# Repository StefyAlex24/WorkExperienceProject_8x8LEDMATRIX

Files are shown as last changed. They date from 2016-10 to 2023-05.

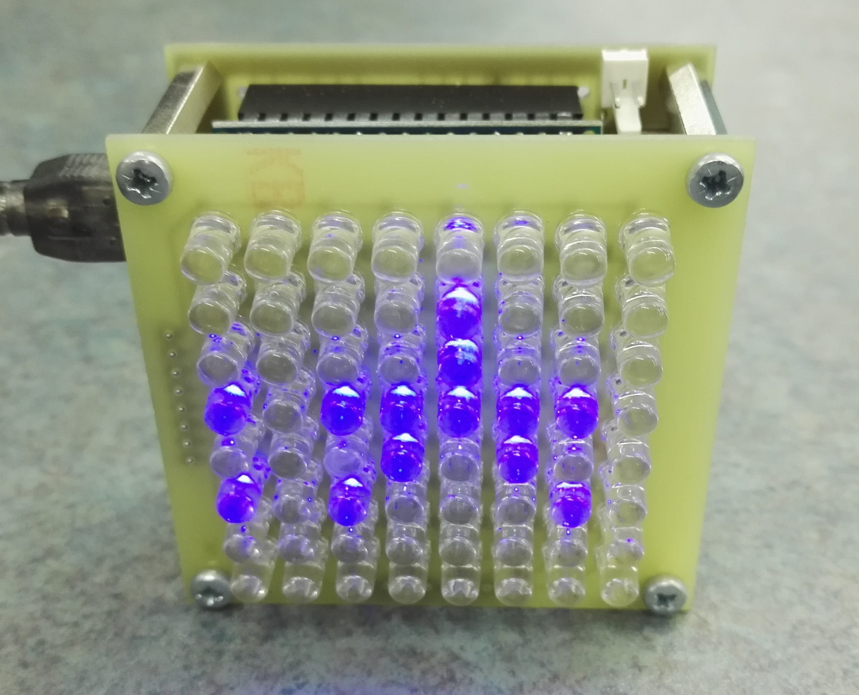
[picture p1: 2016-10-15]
front.jpg

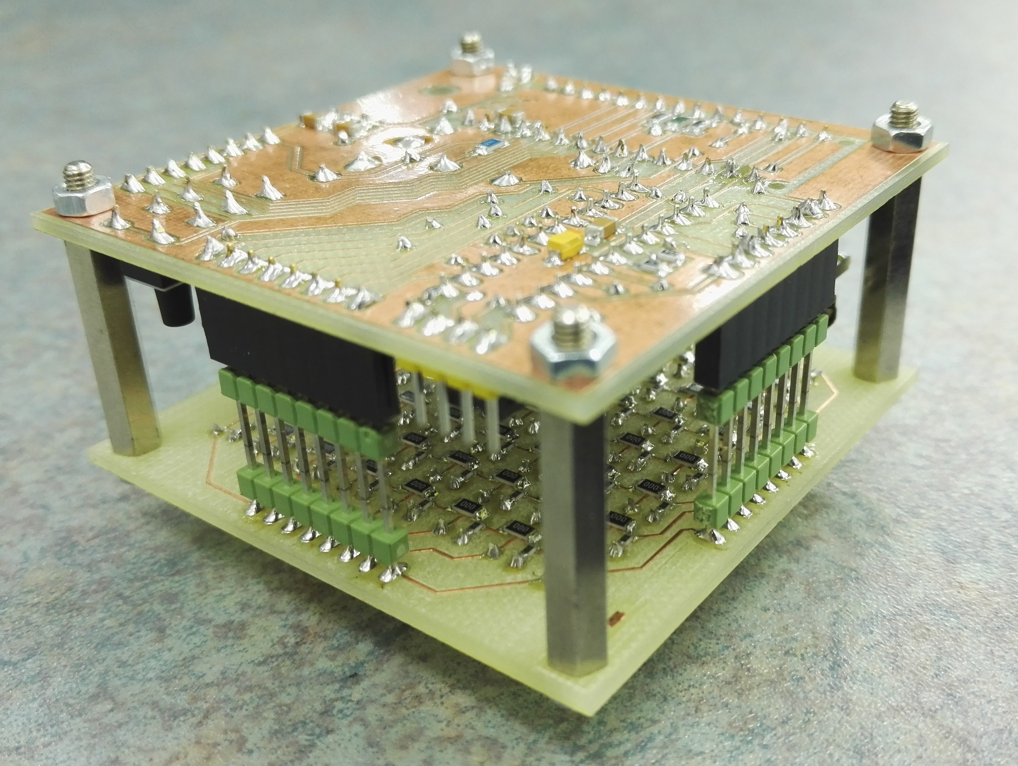
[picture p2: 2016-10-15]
upsidedown.jpg

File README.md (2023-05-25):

# WorkExperienceProject_8x8LEDMATRIX

Arduino Nano based 8x8 LED matrix board with MAX7219 Controller.
Refer to file: 8x8 LED Matrix.docx for project info.
Also includes Arduino Code files to get you started on your journey.

This project is intended as a work experience assignment for school children of age 14 and over.
The code for this project is based off other open source examples with only minor additions and modifications.

Forking of this project is encouraged.

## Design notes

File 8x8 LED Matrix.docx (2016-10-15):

8x8 LED Matrix – Work Experience Project.

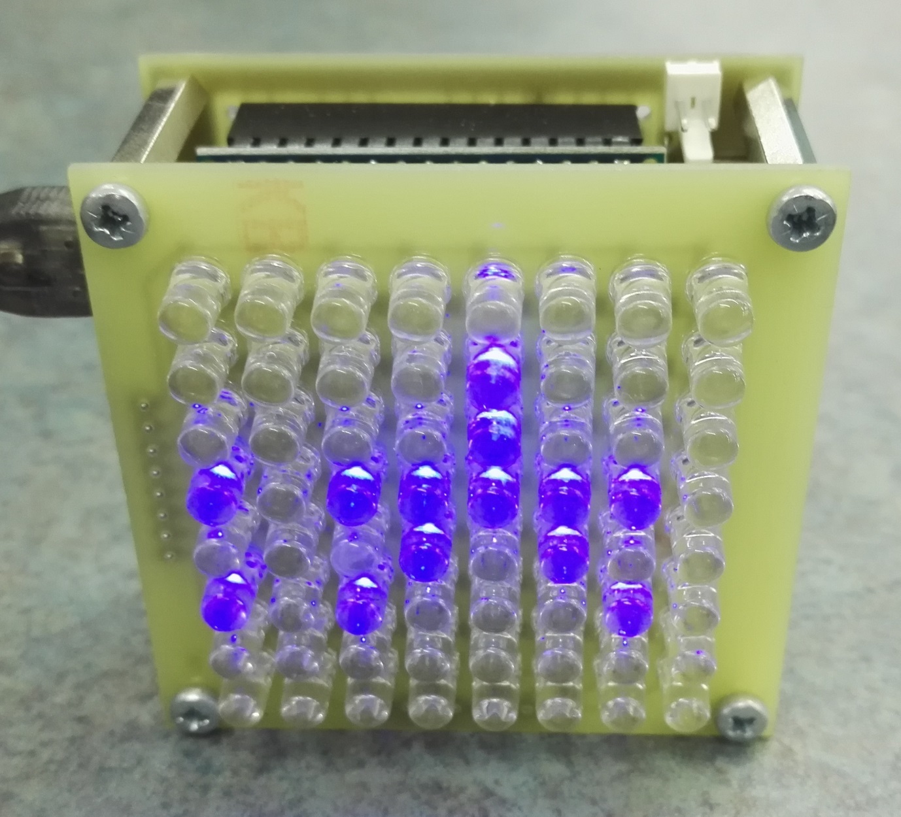
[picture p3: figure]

Objective:

To build an LED matrix board that will display a number of custom messages and (roughly) display the current room temperature.

Skills required:

Component identification, soldering, assembly and programming.

Overview:

Two circuit boards will need to be routed on the PCB router, one for the LED board and the other for the control board. Once populated, both boards will be connected together to create one functional unit.

The first stage is to populate the LED board with 64 5mm LEDs and accompanying current limiting resistors followed by two sets of 2.54mm pitch pin headers.

The LEDs are polarised and must be inserted into the board in the correct orientation before soldering.

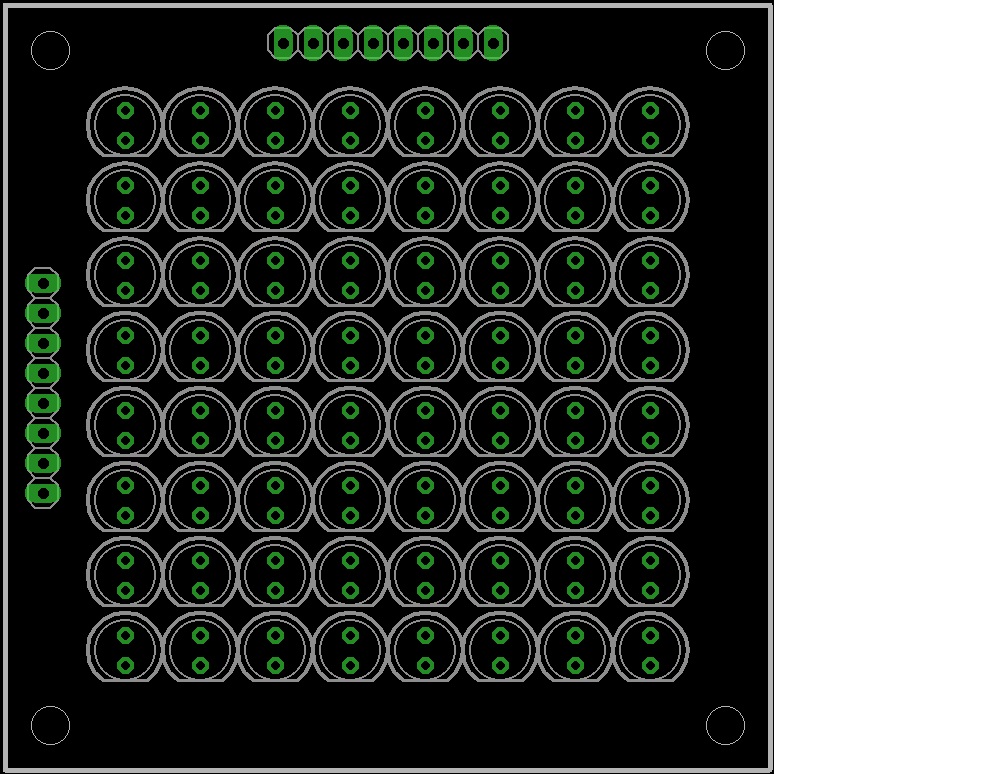
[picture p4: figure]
Z:\WORK EXPERIENCE\8X8 LED MATRIX\BUILD\8X8 TOP PLACEMENT.dib

(This image is a top view of the LED board.)

The resistors should now be soldered on to the underside of the board, the smaller 0603 sized resistors are for current limiting and the larger 1206 sized resisters are 0 ohm jumpers.

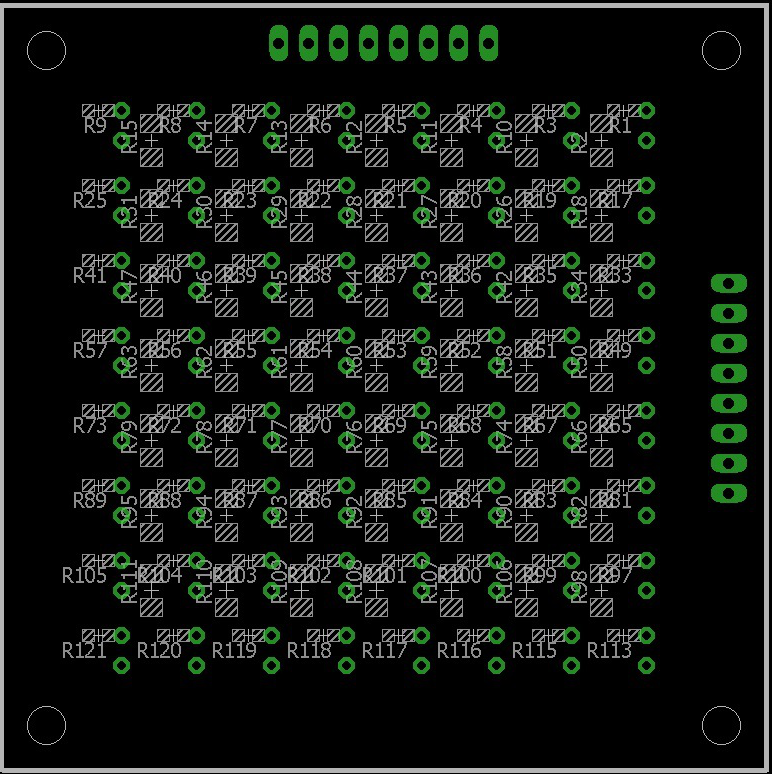
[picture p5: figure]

Next, the headers on the LED board should be soldered into position.

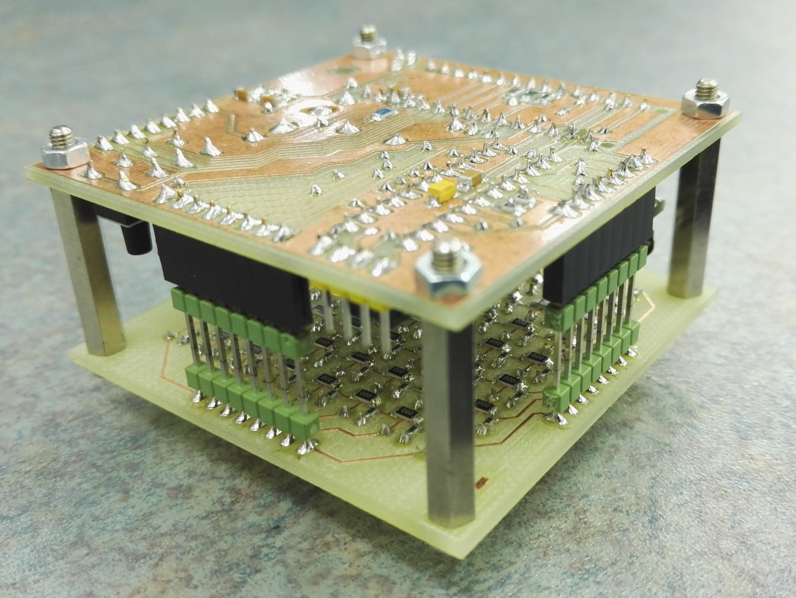
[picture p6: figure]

A small strip of masking tape placed over the holes will help align the pins; they should be flush to the top of the board on the LED side and not standing proud.

Now that the LED board is complete we will move on to the control board.

The control board incorporates a separate micro controller board (Arduino Nano), MAX7219 LED controller chip, power supply, buzzer, thermistor (temperature sensor), push buttons and two extra connectors for future expansion.

All components should be gathered and identified ready for soldering.

Surface mount devices should be soldered first, followed by link wires then through leaded parts; these should be soldered in size order starting from smallest to largest.

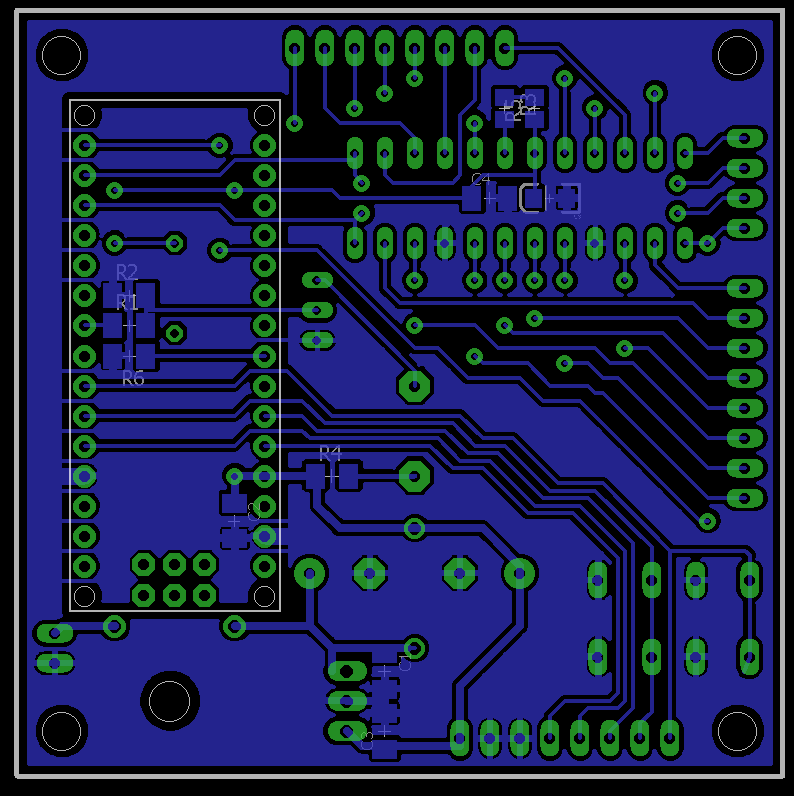
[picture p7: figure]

(This is a view of the underside of the control board.)

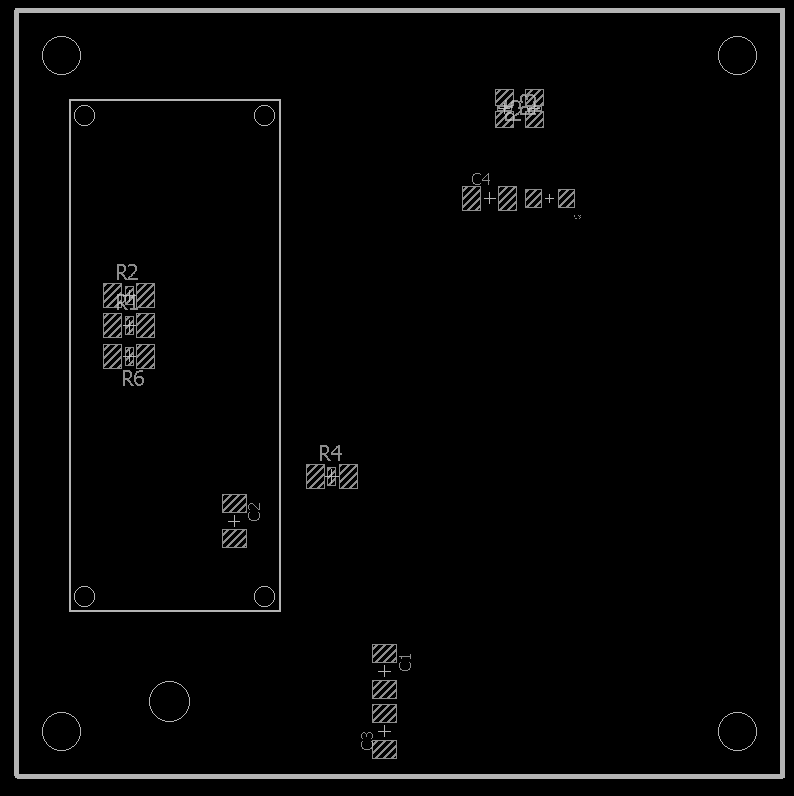
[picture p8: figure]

(This image details the bottom side SMD placement on the control board.)

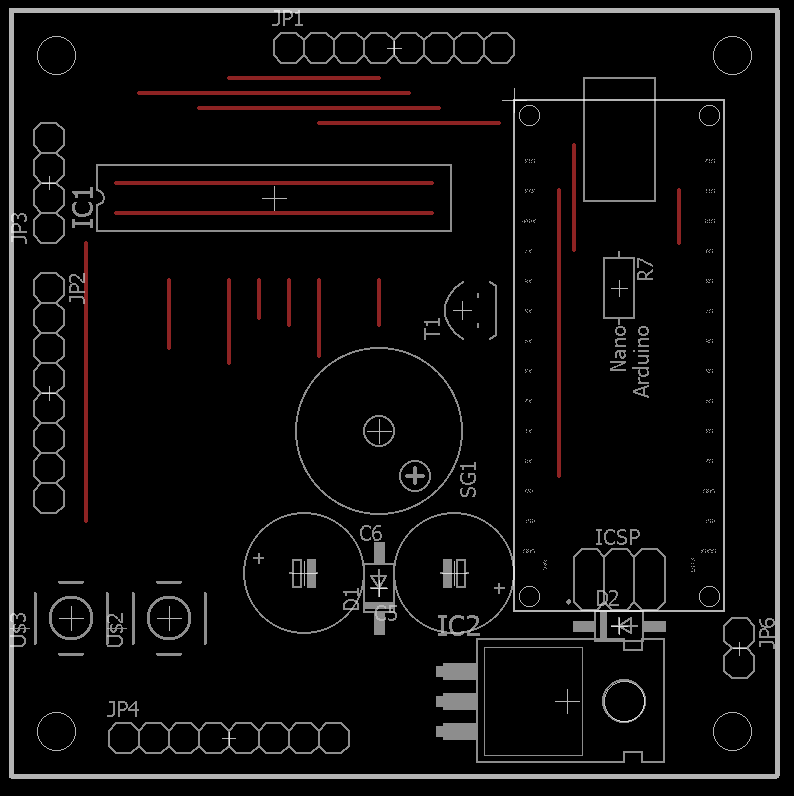
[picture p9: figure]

(The red lines in the above image are link wires that must be placed on top of the board and soldered underneath.)

Once this stage has been completed and checked for errors we will then assemble and program the Arduino board. An Arduino “sketch” and libraries will be provided; at this point you will be able to add up to 9 custom messages to display on the matrix. The sketch will then be compiled and uploaded to the Arduino board using the Arduino IDE software.

Connect the Arduino to the control board; mount the two boards together with 25mm hex pillars and M3 screws. Plug in the USB cable to provide power to the unit.

Messages can be sent to the Arduino over a serial connection at 9600 baud. The serial message will be displayed as string0 in the sketch.

Project info:

Here are the project schematics and parts lists:

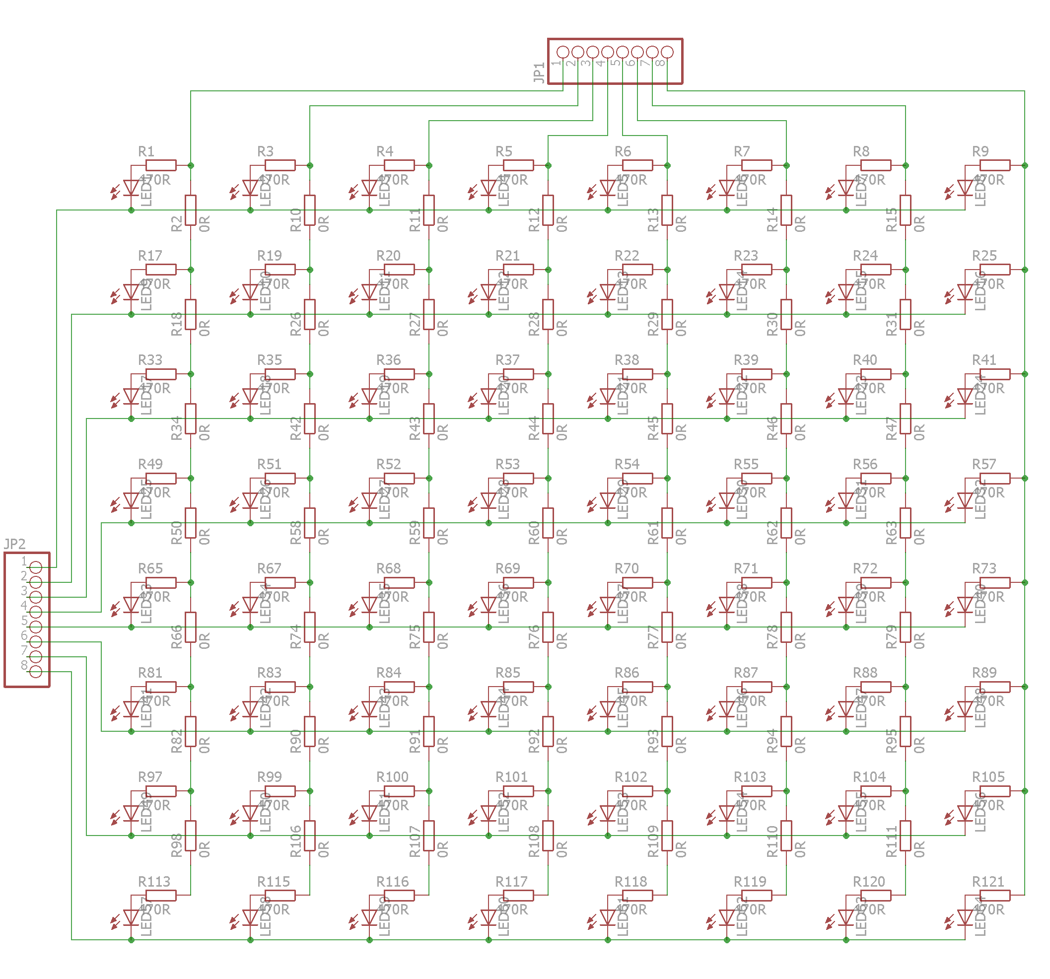
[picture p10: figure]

For the LED board, only four different types of component are used, only the LEDs have a polarity and because the two types of resistors are also different sizes, it would be very hard to build this board incorrectly.

LED5MM led

470R R0603

0R R1206

1X08 pinhead

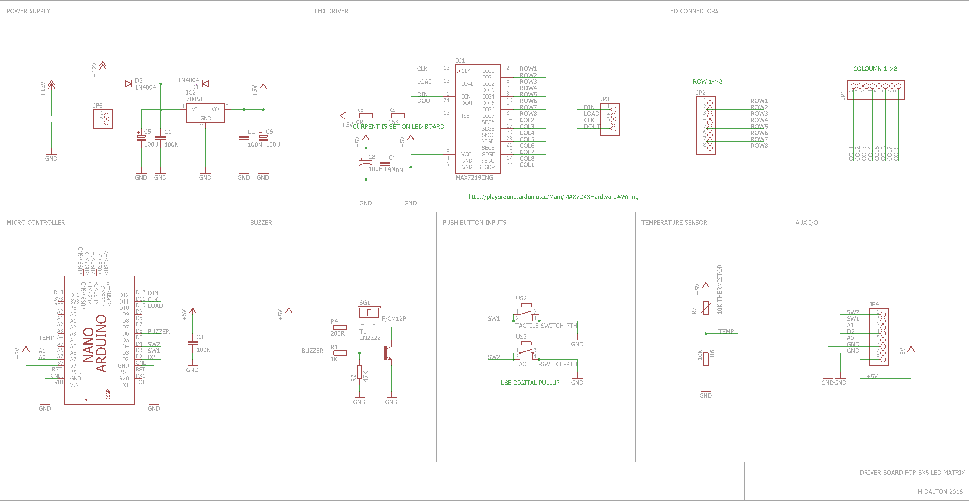
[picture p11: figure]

This is the parts list for the driver board.

Partlist

Part Value Device Package

C1 100N C-EUC1206K C1206K

C2 100N C-EUC1206K C1206K

C3 100N C-EUC1206K C1206K

C4 100N C-EUC1206K C1206K

C5 100U CPOL-EUE5-10.5 E5-10,5

C6 100U CPOL-EUE5-10.5 E5-10,5

C8 10uF TANT 10UF-TANT EIA3216

D1 1N4004 1N4004 DO41-10

D2 1N4004 1N4004 DO41-10

IC1 MAX7219CNG MAX7219CNG DIL24-3

IC2 7805T 7805T TO220H

JP1 PINHD-1X8 1X08

JP2 PINHD-1X8 1X08

JP3 PINHD-1X4 1X04

JP4 PINHD-1X8 1X08

JP6 PINHD-1X2 1X02

PCB1 ARDUINO ARDUINO_NANO ARDUINO_NANO

R1 1K R-EU_M1206 M1206

R2 47K R-EU_M1206 M1206

R3 15K R-EU_M0805 M0805

R4 200R R-EU_M1206 M1206

R5 0R R-EU_M0805 M0805

R6 10K R-EU_M1206 M1206

R7 10K THERMISTOR-7,5 R-7,5

SG1 F/CM12P BUZZER F/CM12P

T1 2N2222 2N2222 TO92-EBC-OVAL

U$2 SWITCH TACTILE-SWITCH-PTH TAC-SWITCH-PTH

U$3 SWITCH TACTILE-SWITCH-PTH TAC-SWITCH-PTH

Extra features:

The control board has some unused hardware for future expansion.

Two momentary push buttons and a buzzer are connected to the Arduino as well as an expansion header for both the Arduino and the Maxim LED driver chip. Extra features may be added into the code for greater functionality.

Multiple LED matrixes may be daisy chained and controlled by the Arduino as long as each matrix has its own controller IC.

A two pin power connector is present to allow the unit to be powered by a 9V battery; this connector is connected to a linear 5 volt regulator which will power both the LED and control boards.

The Code:

The following is the exact code used in this project. It is dependent on the MaxMatrix library made by Oscar Kin-Chung Au. (https://code.google.com/archive/p/arudino-maxmatrix-library/downloads)

Arduino IDE Download links: https://www.arduino.cc/en/Main/Software & http://www.arduino.org/downloads

The entire project can be viewed at: https://github.com/SlyMike/WorkExperienceProject_8x8LEDMATRIX

/*

# 8x8 LED matrix with temperature measurement and serial input. #

# Code taken from Marcelo Moraes, July 9th, 2013 & Arduino playground. #

# visit this web page for further information about MaxMatrix library #

# https://code.google.com/p/arudino-maxmatrix-library/ #

# This code is a public example. #

# Rehashed by Mick Dalton, 2016. #

*/

#include <MaxMatrix.h>

#include <avr/pgmspace.h>

//thermistor start

#include <math.h>

double ThermistorC(int RawADC) {

double Temp;

Temp = log(10000.0 * ((1024.0 / RawADC - 1)));

Temp = 1 / (0.001129148 + (0.000234125 + (0.0000000876741 * Temp * Temp )) * Temp );

Temp = Temp - 273.15;

return Temp;

}//thermistor end

PROGMEM const char CH[] = {

3, 8, B00000000, B00000000, B00000000, B00000000, B00000000, // space

1, 8, B01011111, B00000000, B00000000, B00000000, B00000000, // !

3, 8, B00000011, B00000000, B00000011, B00000000, B00000000, // "

5, 8, B00010100, B00111110, B00010100, B00111110, B00010100, // #

4, 8, B00100100, B01101010, B00101011, B00010010, B00000000, // $

5, 8, B01100011, B00010011, B00001000, B01100100, B01100011, // %

5, 8, B00110110, B01001001, B01010110, B00100000, B01010000, // &

1, 8, B00000011, B00000000, B00000000, B00000000, B00000000, // '

3, 8, B00011100, B00100010, B01000001, B00000000, B00000000, // (

3, 8, B01000001, B00100010, B00011100, B00000000, B00000000, // )

5, 8, B00101000, B00011000, B00001110, B00011000, B00101000, // *

5, 8, B00001000, B00001000, B00111110, B00001000, B00001000, // +

2, 8, B10110000, B01110000, B00000000, B00000000, B00000000, // ,

4, 8, B00001000, B00001000, B00001000, B00001000, B00000000, // -

2, 8, B01100000, B01100000, B00000000, B00000000, B00000000, // .

4, 8, B01100000, B00011000, B00000110, B00000001, B00000000, // /

4, 8, B00111110, B01000001, B01000001, B00111110, B00000000, // 0

3, 8, B01000010, B01111111, B01000000, B00000000, B00000000, // 1

4, 8, B01100010, B01010001, B01001001, B01000110, B00000000, // 2

4, 8, B00100010, B01000001, B01001001, B00110110, B00000000, // 3

4, 8, B00011000, B00010100, B00010010, B01111111, B00000000, // 4

4, 8, B00100111, B01000101, B01000101, B00111001, B00000000, // 5

4, 8, B00111110, B01001001, B01001001, B00110000, B00000000, // 6

4, 8, B01100001, B00010001, B00001001, B00000111, B00000000, // 7

4, 8, B00110110, B01001001, B01001001, B00110110, B00000000, // 8

4, 8, B00000110, B01001001, B01001001, B00111110, B00000000, // 9

2, 8, B01010000, B00000000, B00000000, B00000000, B00000000, // :

2, 8, B10000000, B01010000, B00000000, B00000000, B00000000, // ;

3, 8, B00010000, B00101000, B01000100, B00000000, B00000000, // <

3, 8, B00010100, B00010100, B00010100, B00000000, B00000000, // =

3, 8, B01000100, B00101000, B00010000, B00000000, B00000000, // >

4, 8, B00000010, B01011001, B00001001, B00000110, B00000000, // ?

5, 8, B00111110, B01001001, B01010101, B01011101, B00001110, // @

4, 8, B01111110, B00010001, B00010001, B01111110, B00000000, // A

4, 8, B01111111, B01001001, B01001001, B00110110, B00000000, // B

4, 8, B00111110, B01000001, B01000001, B00100010, B00000000, // C

4, 8, B01111111, B01000001, B01000001, B00111110, B00000000, // D

4, 8, B01111111, B01001001, B01001001, B01000001, B00000000, // E

4, 8, B01111111, B00001001, B00001001, B00000001, B00000000, // F

4, 8, B00111110, B01000001, B01001001, B01111010, B00000000, // G

4, 8, B01111111, B00001000, B00001000, B01111111, B00000000, // H

3, 8, B01000001, B01111111, B01000001, B00000000, B00000000, // I

4, 8, B00110000, B01000000, B01000001, B00111111, B00000000, // J

4, 8, B01111111, B00001000, B00010100, B01100011, B00000000, // K

4, 8, B01111111, B01000000, B01000000, B01000000, B00000000, // L

5, 8, B01111111, B00000010, B00001100, B00000010, B01111111, // M

5, 8, B01111111, B00000100, B00001000, B00010000, B01111111, // N

4, 8, B00111110, B01000001, B01000001, B00111110, B00000000, // O

4, 8, B01111111, B00001001, B00001001, B00000110, B00000000, // P

4, 8, B00111110, B01000001, B01000001, B10111110, B00000000, // Q

4, 8, B01111111, B00001001, B00001001, B01110110, B00000000, // R

4, 8, B01000110, B01001001, B01001001, B00110010, B00000000, // S

5, 8, B00000001, B00000001, B01111111, B00000001, B00000001, // T

4, 8, B00111111, B01000000, B01000000, B00111111, B00000000, // U

5, 8, B00001111, B00110000, B01000000, B00110000, B00001111, // V

5, 8, B00111111, B01000000, B00111000, B01000000, B00111111, // W

5, 8, B01100011, B00010100, B00001000, B00010100, B01100011, // X

5, 8, B00000111, B00001000, B01110000, B00001000, B00000111, // Y

4, 8, B01100001, B01010001, B01001001, B01000111, B00000000, // Z

2, 8, B01111111, B01000001, B00000000, B00000000, B00000000, // [

4, 8, B00000001, B00000110, B00011000, B01100000, B00000000, // \ backslash

2, 8, B01000001, B01111111, B00000000, B00000000, B00000000, // ]

3, 8, B00000010, B00000001, B00000010, B00000000, B00000000, // hat

4, 8, B01000000, B01000000, B01000000, B01000000, B00000000, // _

2, 8, B00000001, B00000010, B00000000, B00000000, B00000000, // `

4, 8, B00100000, B01010100, B01010100, B01111000, B00000000, // a

4, 8, B01111111, B01000100, B01000100, B00111000, B00000000, // b

4, 8, B00111000, B01000100, B01000100, B00101000, B00000000, // c

4, 8, B00111000, B01000100, B01000100, B01111111, B00000000, // d

4, 8, B00111000, B01010100, B01010100, B00011000, B00000000, // e

3, 8, B00000100, B01111110, B00000101, B00000000, B00000000, // f

4, 8, B10011000, B10100100, B10100100, B01111000, B00000000, // g

4, 8, B01111111, B00000100, B00000100, B01111000, B00000000, // h

3, 8, B01000100, B01111101, B01000000, B00000000, B00000000, // i

4, 8, B01000000, B10000000, B10000100, B01111101, B00000000, // j

4, 8, B01111111, B00010000, B00101000, B01000100, B00000000, // k

3, 8, B01000001, B01111111, B01000000, B00000000, B00000000, // l

5, 8, B01111100, B00000100, B01111100, B00000100, B01111000, // m

4, 8, B01111100, B00000100, B00000100, B01111000, B00000000, // n

4, 8, B00111000, B01000100, B01000100, B00111000, B00000000, // o

4, 8, B11111100, B00100100, B00100100, B00011000, B00000000, // p

4, 8, B00011000, B00100100, B00100100, B11111100, B00000000, // q

4, 8, B01111100, B00001000, B00000100, B00000100, B00000000, // r

4, 8, B01001000, B01010100, B01010100, B00100100, B00000000, // s

3, 8, B00000100, B00111111, B01000100, B00000000, B00000000, // t

4, 8, B00111100, B01000000, B01000000, B01111100, B00000000, // u

5, 8, B00011100, B00100000, B01000000, B00100000, B00011100, // v

5, 8, B00111100, B01000000, B00111100, B01000000, B00111100, // w

5, 8, B01000100, B00101000, B00010000, B00101000, B01000100, // x

4, 8, B10011100, B10100000, B10100000, B01111100, B00000000, // y

3, 8, B01100100, B01010100, B01001100, B00000000, B00000000, // z

3, 8, B00001000, B00110110, B01000001, B00000000, B00000000, // {

1, 8, B01111111, B00000000, B00000000, B00000000, B00000000, // |

3, 8, B01000001, B00110110, B00001000, B00000000, B00000000, // }

4, 8, B00001000, B00000100, B00001000, B00000100, B00000000, // ~

};

int data = 12; // DIN pin of MAX7219 module

int load = 10; // CS pin of MAX7219 module

int clock = 11; // CLK pin of MAX7219 module

int maxInUse = 1; //change this variable to set how many MAX7219's you'll use

MaxMatrix m(data, load, clock, maxInUse); // define module

byte buffer[10];

char string1[] = " line1 ";

char string2[] = " line2 ";

char string3[] = " line3 ";

char string4[] = " line4 ";

char string5[] = " line5 ";

// DO NOT ALTER THE LINE BELOW.

char string6[] = " * Temp XX.XXc * ";

char string7[] = "LOW BRIGHTNESS!!!! ";

char string8[] = "MEDIUM BRIGHTNESS!!!! ";

char string9[] = "NORMAL BRIGHTNESS!!!! ";

char string10[] = "MAXIMUM BRIGHTNESS!!!! ";

const int buzzer = 6;

const int button1 = 3;

const int button2 = 4;

const int io2 = 2;

// add 2 more io's

void setup() {

pinMode(buzzer, OUTPUT);

pinMode(button1, INPUT_PULLUP);

pinMode(button2, INPUT_PULLUP);

pinMode(io2, INPUT);

m.init(); // module initialize

m.setIntensity(15); // dot matix intensity 0-15

Serial.begin(9600); // serial communication initialize

}

void loop() {

//thermistor start

int valC;

double tempC;

valC = analogRead(A4);

tempC = ThermistorC(valC);

Serial.print("Temperature = ");

Serial.print(tempC);

Serial.println(" C");

int TempDigit1 = floor((int)(tempC) % 10);

int TempDigit2 = (int)tempC / 10;

int TempDigit3 = (int)(tempC * 10) - ((int)(tempC) * 10);

int TempDigit4 = (int)(tempC * 100) - ((int)(tempC) * 100) - (TempDigit3 * 10);

string6[8] = TempDigit2 + 48; //5

string6[9] = TempDigit1 + 48; //6

string6[11] = TempDigit3 + 48; //8

string6[12] = TempDigit4 + 48; //9

//thermistor end

// only use 1 serial port at any given time!

// this is the code if you want to enter a message via USB serial console

while (Serial.available() > 0) {

byte c = Serial.read();

Serial.println(c, DEC);

printCharWithShift(c, 100);

}

delay(100);

m.shiftLeft(false, true);

m.setIntensity(5);

// print the active sentences, "//" out any line to ignore it.

printStringWithShift(string1, 70);

printStringWithShift(string2, 70);

printStringWithShift(string3, 70);

printStringWithShift(string4, 70);

printStringWithShift(string5, 70);

printStringWithShift(string6, 70);

m.setIntensity(1); // dot matix intensity 0-15

printStringWithShift(string7, 80);

m.setIntensity(5); // dot matix intensity 0-15

printStringWithShift(string8, 80);

m.setIntensity(10); // dot matix intensity 0-15

printStringWithShift(string9, 80);

m.setIntensity(15); // dot matix intensity 0-15

printStringWithShift(string10, 80);

m.setIntensity(10); // dot matix intensity 0-15

}

void printCharWithShift(char c, int shift_speed) {

if (c < 32) return;

c -= 32;

memcpy_P(buffer, CH + 7 * c, 7);

m.writeSprite(maxInUse * 8, 0, buffer);

m.setColumn(maxInUse * 8 + buffer[0], 0);

for (int i = 0; i < buffer[0] + 1; i++)

{

delay(shift_speed);

m.shiftLeft(false, false);

}

}

void printStringWithShift(char* s, int shift_speed) {

while (*s != 0) {

printCharWithShift(*s, shift_speed);

s++;

}

}

//end of sketch

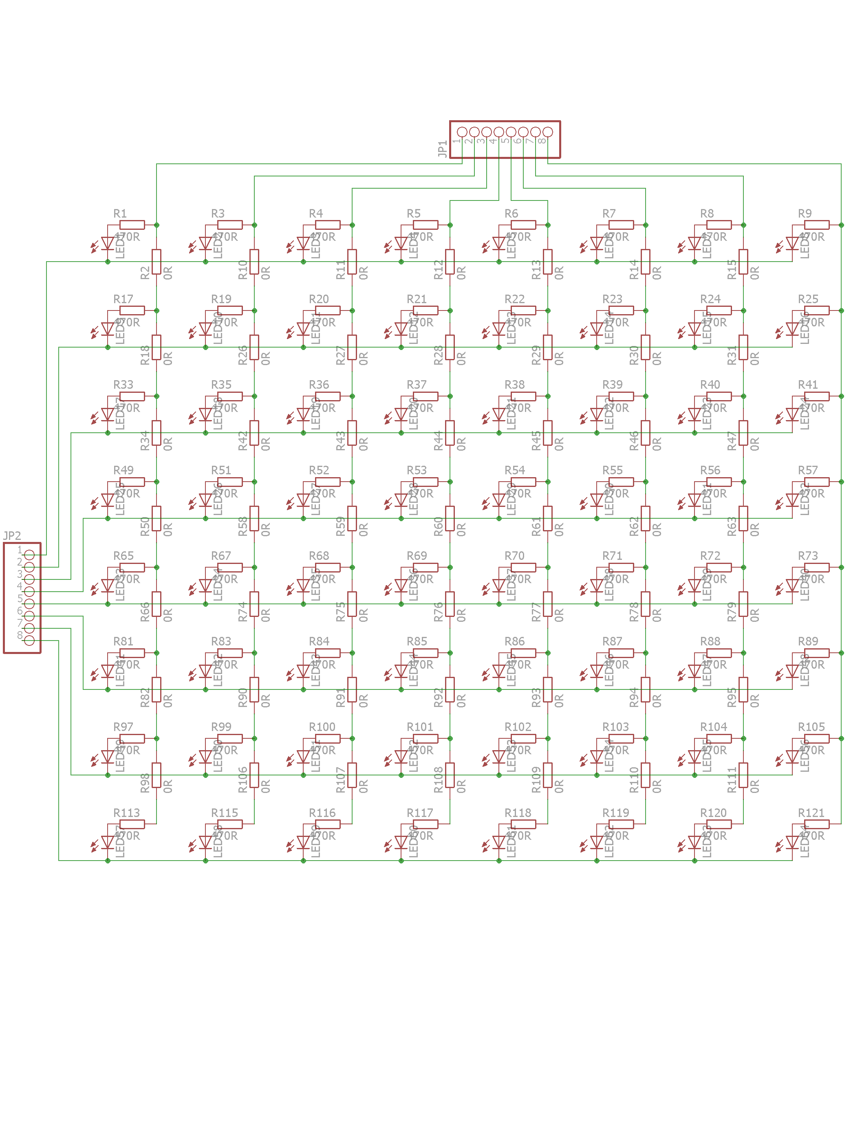
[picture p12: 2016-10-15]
led board.png

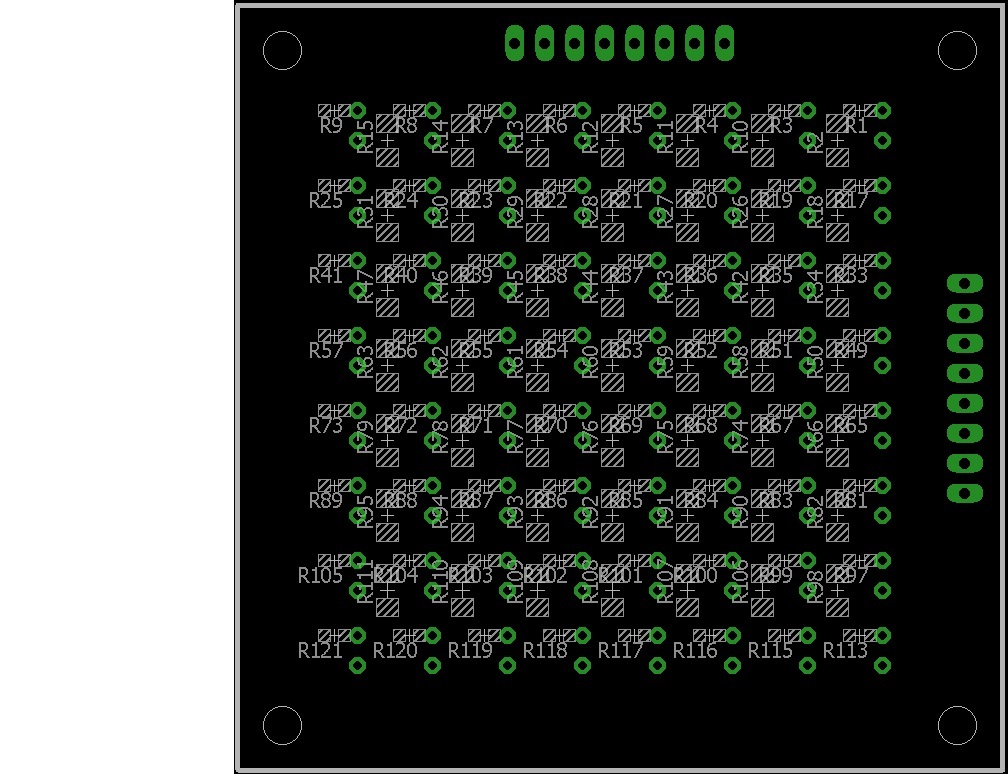
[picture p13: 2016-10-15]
8X8 BOTTOM SMD.jpg

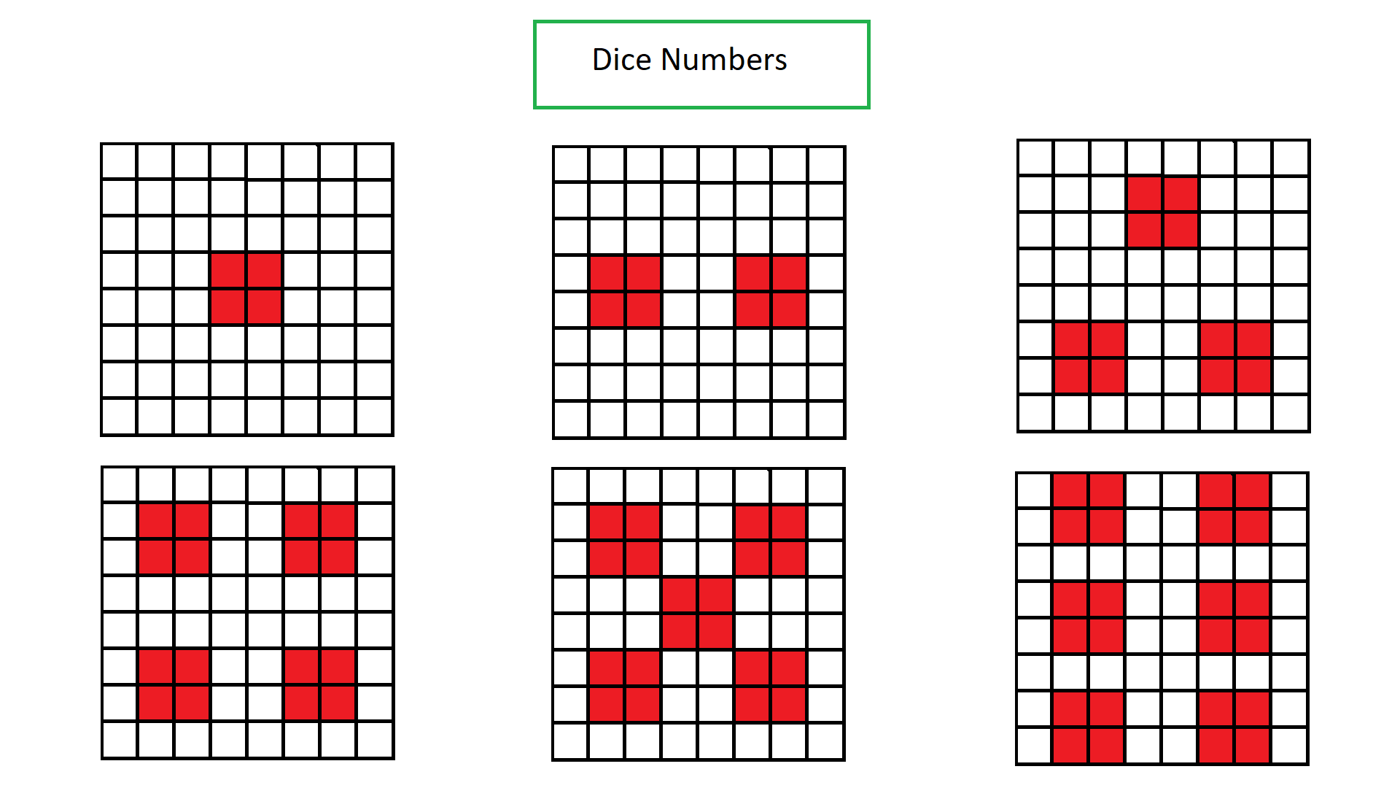
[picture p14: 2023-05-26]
RandomVirtualDice_PushButton_LEDMatrix/Dice NO. Referance for 8x8 LEDMatrix.png

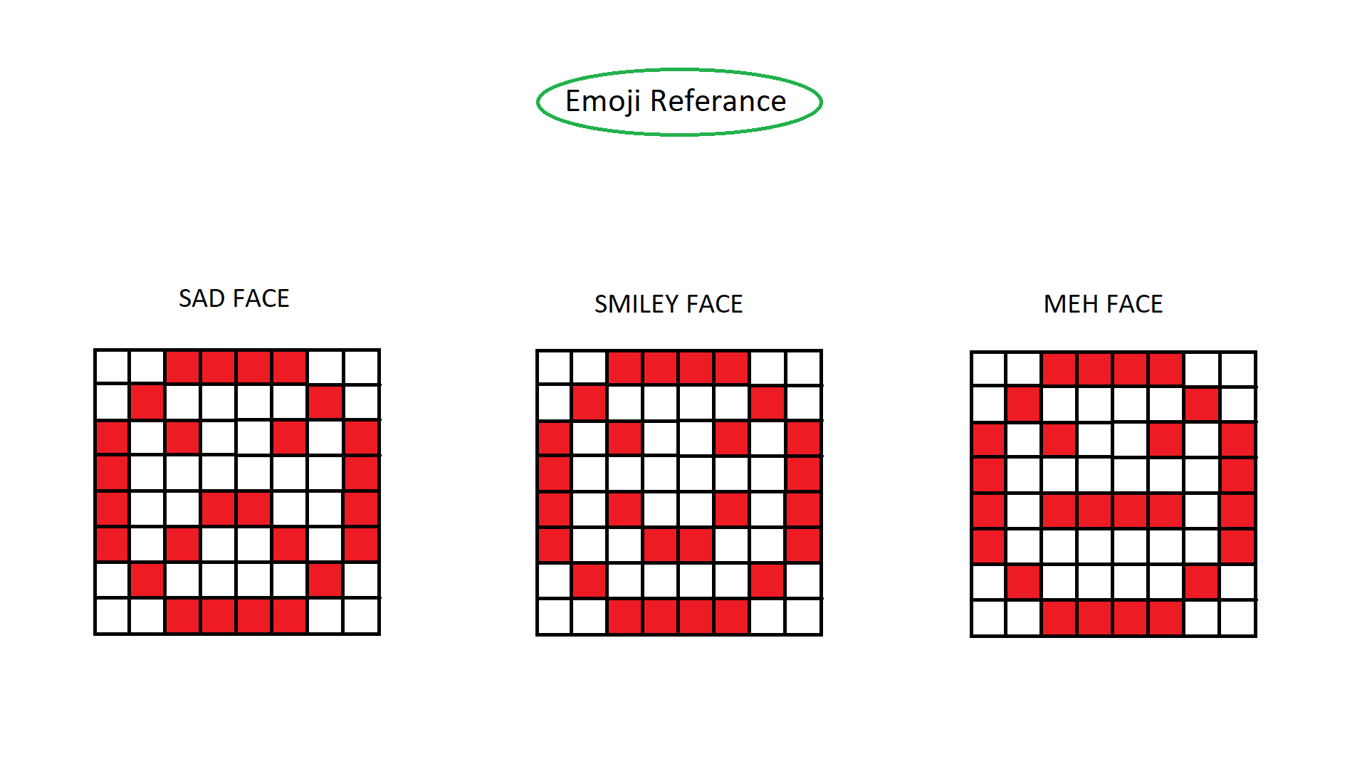
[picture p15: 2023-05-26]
LEDMatrix_SadHappyFace_PushButtons_Example02/Emoji Referance for 8x8 LEDMatrix.png

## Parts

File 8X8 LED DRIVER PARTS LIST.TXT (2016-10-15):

Partlist

Exported from 8x8 led matrix MAX DRIVER.sch at 16/08/2016 16:16

EAGLE Version 7.5.0 Copyright (c) 1988-2015 CadSoft

Assembly variant: 

Part     Value              Device             Package        Library               Sheet

C1       100N               C-EUC1206K         C1206K         rcl                   1
C2       100N               C-EUC1206K         C1206K         rcl                   1
C3       100N               C-EUC1206K         C1206K         rcl                   1
C4       100N               C-EUC1206K         C1206K         rcl                   1
C5       100U               CPOL-EUE5-10.5     E5-10,5        rcl                   1
C6       100U               CPOL-EUE5-10.5     E5-10,5        rcl                   1
C8       10uF TANT          10UF-TANT          EIA3216        SparkFun-Retired      1
D1       1N4004             1N4004             DO41-10        diode                 1
D2       1N4004             1N4004             DO41-10        adafruit              1
IC1      MAX7219CNG         MAX7219CNG         DIL24-3        maxim                 1
IC2      7805T              7805T              TO220H         adafruit              1
JP1                         PINHD-1X8          1X08           pinhead               1
JP2                         PINHD-1X8          1X08           pinhead               1
JP3                         PINHD-1X4          1X04           pinhead               1
JP4                         PINHD-1X8          1X08           pinhead               1
JP6                         PINHD-1X2          1X02           pinhead               1
PCB1     ARDUINO_NANO       ARDUINO_NANO       ARDUINO_NANO   E14_Arduino_published 1
R1       1K                 R-EU_M1206         M1206          rcl                   1
R2       47K                R-EU_M1206         M1206          rcl                   1
R3       15K                R-EU_M0805         M0805          rcl                   1
R4       200R               R-EU_M1206         M1206          rcl                   1
R5       0R                 R-EU_M0805         M0805          rcl                   1
R6       10K                R-EU_M1206         M1206          rcl                   1
R7       10K THERMISTOR     THERMISTOR-7,5     R-7,5          varistor              1
SG1      F/CM12P            F/CM12P            F/CM12P        buzzer                1
T1       2N2222             2N2222             TO92-EBC-OVAL  adafruit              1
U$2      TACTILE-SWITCH-PTH TACTILE-SWITCH-PTH TAC-SWITCH-PTH GeekAmmo              1
U$3      TACTILE-SWITCH-PTH TACTILE-SWITCH-PTH TAC-SWITCH-PTH GeekAmmo              1

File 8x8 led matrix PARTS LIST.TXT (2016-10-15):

Partlist

Exported from 8x8 led matrix.brd at 16/08/2016 16:32

EAGLE Version 7.5.0 Copyright (c) 1988-2015 CadSoft

Assembly variant: 

Part     Value          Package  Library  Position (mm)         Orientation

JP1                     1X08     pinhead  (46.355 73.025)       R0
JP2                     1X08     pinhead  (17.145 43.815)       R270
LED1                    LED5MM   led      (24.13 66.04)         R270
LED2                    LED5MM   led      (30.48 66.04)         R270
LED3                    LED5MM   led      (36.83 66.04)         R270
LED4                    LED5MM   led      (43.18 66.04)         R270
LED5                    LED5MM   led      (49.53 66.04)         R270
LED6                    LED5MM   led      (55.88 66.04)         R270
LED7                    LED5MM   led      (62.23 66.04)         R270
LED8                    LED5MM   led      (68.58 66.04)         R270
LED9                    LED5MM   led      (24.13 59.69)         R270
LED10                   LED5MM   led      (30.48 59.69)         R270
LED11                   LED5MM   led      (36.83 59.69)         R270
LED12                   LED5MM   led      (43.18 59.69)         R270
LED13                   LED5MM   led      (49.53 59.69)         R270
LED14                   LED5MM   led      (55.88 59.69)         R270
LED15                   LED5MM   led      (62.23 59.69)         R270
LED16                   LED5MM   led      (68.58 59.69)         R270
LED17                   LED5MM   led      (24.13 53.34)         R270
LED18                   LED5MM   led      (30.48 53.34)         R270
LED19                   LED5MM   led      (36.83 53.34)         R270
LED20                   LED5MM   led      (43.18 53.34)         R270
LED21                   LED5MM   led      (49.53 53.34)         R270
LED22                   LED5MM   led      (55.88 53.34)         R270
LED23                   LED5MM   led      (62.23 53.34)         R270
LED24                   LED5MM   led      (68.58 53.34)         R270
LED25                   LED5MM   led      (24.13 46.99)         R270
LED26                   LED5MM   led      (30.48 46.99)         R270
LED27                   LED5MM   led      (36.83 46.99)         R270
LED28                   LED5MM   led      (43.18 46.99)         R270
LED29                   LED5MM   led      (49.53 46.99)         R270
LED30                   LED5MM   led      (55.88 46.99)         R270
LED31                   LED5MM   led      (62.23 46.99)         R270
LED32                   LED5MM   led      (68.58 46.99)         R270
LED33                   LED5MM   led      (24.13 40.64)         R270
LED34                   LED5MM   led      (30.48 40.64)         R270
LED35                   LED5MM   led      (36.83 40.64)         R270
LED36                   LED5MM   led      (43.18 40.64)         R270
LED37                   LED5MM   led      (49.53 40.64)         R270
LED38                   LED5MM   led      (55.88 40.64)         R270
LED39                   LED5MM   led      (62.23 40.64)         R270
LED40                   LED5MM   led      (68.58 40.64)         R270
LED41                   LED5MM   led      (24.13 34.29)         R270
LED42                   LED5MM   led      (30.48 34.29)         R270
LED43                   LED5MM   led      (36.83 34.29)         R270
LED44                   LED5MM   led      (43.18 34.29)         R270
LED45                   LED5MM   led      (49.53 34.29)         R270
LED46                   LED5MM   led      (55.88 34.29)         R270
LED47                   LED5MM   led      (62.23 34.29)         R270
LED48                   LED5MM   led      (68.58 34.29)         R270
LED49                   LED5MM   led      (24.13 27.94)         R270
LED50                   LED5MM   led      (30.48 27.94)         R270
LED51                   LED5MM   led      (36.83 27.94)         R270
LED52                   LED5MM   led      (43.18 27.94)         R270
LED53                   LED5MM   led      (49.53 27.94)         R270
LED54                   LED5MM   led      (55.88 27.94)         R270
LED55                   LED5MM   led      (62.23 27.94)         R270
LED56                   LED5MM   led      (68.58 27.94)         R270
LED57                   LED5MM   led      (24.13 21.59)         R270
LED58                   LED5MM   led      (30.48 21.59)         R270
LED59                   LED5MM   led      (36.83 21.59)         R270
LED60                   LED5MM   led      (43.18 21.59)         R270
LED61                   LED5MM   led      (49.53 21.59)         R270
LED62                   LED5MM   led      (55.88 21.59)         R270
LED63                   LED5MM   led      (62.23 21.59)         R270
LED64                   LED5MM   led      (68.58 21.59)         R270
R1       470R           R0603    resistor (26.035 67.31)        MR180
R2       0R             R1206    resistor (27.94 64.77)         MR90
R3       470R           R0603    resistor (32.385 67.31)        MR180
R4       470R           R0603    resistor (38.735 67.31)        MR180
R5       470R           R0603    resistor (45.085 67.31)        MR180
R6       470R           R0603    resistor (51.435 67.31)        MR180
R7       470R           R0603    resistor (57.785 67.31)        MR180
R8       470R           R0603    resistor (64.135 67.31)        MR180
R9       470R           R0603    resistor (70.485 67.31)        MR180
R10      0R             R1206    resistor (34.29 64.77)         MR90
R11      0R             R1206    resistor (40.64 64.77)         MR90
R12      0R             R1206    resistor (46.99 64.77)         MR90
R13      0R             R1206    resistor (53.34 64.77)         MR90
R14      0R             R1206    resistor (59.69 64.77)         MR90
R15      0R             R1206    resistor (66.04 64.77)         MR90
R17      470R           R0603    resistor (26.035 60.96)        MR180
R18      0R             R1206    resistor (27.94 58.42)         MR90
R19      470R           R0603    resistor (32.385 60.96)        MR180
R20      470R           R0603    resistor (38.735 60.96)        MR180
R21      470R           R0603    resistor (45.085 60.96)        MR180
R22      470R           R0603    resistor (51.435 60.96)        MR180
R23      470R           R0603    resistor (57.785 60.96)        MR180
R24      470R           R0603    resistor (64.135 60.96)        MR180
R25      470R           R0603    resistor (70.485 60.96)        MR180
R26      0R             R1206    resistor (34.29 58.42)         MR90
R27      0R             R1206    resistor (40.64 58.42)         MR90
R28      0R             R1206    resistor (46.99 58.42)         MR90
R29      0R             R1206    resistor (53.34 58.42)         MR90
R30      0R             R1206    resistor (59.69 58.42)         MR90
R31      0R             R1206    resistor (66.04 58.42)         MR90
R33      470R           R0603    resistor (26.035 54.61)        MR180
R34      0R             R1206    resistor (27.94 52.07)         MR90
R35      470R           R0603    resistor (32.385 54.61)        MR180
R36      470R           R0603    resistor (38.735 54.61)        MR180
R37      470R           R0603    resistor (45.085 54.61)        MR180
R38      470R           R0603    resistor (51.435 54.61)        MR180
R39      470R           R0603    resistor (57.785 54.61)        MR180
R40      470R           R0603    resistor (64.135 54.61)        MR180
R41      470R           R0603    resistor (70.485 54.61)        MR180
R42      0R             R1206    resistor (34.29 52.07)         MR90
R43      0R             R1206    resistor (40.64 52.07)         MR90
R44      0R             R1206    resistor (46.99 52.07)         MR90
R45      0R             R1206    resistor (53.34 52.07)         MR90
R46      0R             R1206    resistor (59.69 52.07)         MR90
R47      0R             R1206    resistor (66.04 52.07)         MR90
R49      470R           R0603    resistor (26.035 48.26)        MR180
R50      0R             R1206    resistor (27.94 45.72)         MR90
R51      470R           R0603    resistor (32.385 48.26)        MR180
R52      470R           R0603    resistor (38.735 48.26)        MR180
R53      470R           R0603    resistor (45.085 48.26)        MR180
R54      470R           R0603    resistor (51.435 48.26)        MR180
R55      470R           R0603    resistor (57.785 48.26)        MR180
R56      470R           R0603    resistor (64.135 48.26)        MR180
R57      470R           R0603    resistor (70.485 48.26)        MR180
R58      0R             R1206    resistor (34.29 45.72)         MR90
R59      0R             R1206    resistor (40.64 45.72)         MR90
R60      0R             R1206    resistor (46.99 45.72)         MR90
R61      0R             R1206    resistor (53.34 45.72)         MR90
R62      0R             R1206    resistor (59.69 45.72)         MR90
R63      0R             R1206    resistor (66.04 45.72)         MR90
R65      470R           R0603    resistor (26.035 41.91)        MR180
R66      0R             R1206    resistor (27.94 39.37)         MR90
R67      470R           R0603    resistor (32.385 41.91)        MR180
R68      470R           R0603    resistor (38.735 41.91)        MR180
R69      470R           R0603    resistor (45.085 41.91)        MR180
R70      470R           R0603    resistor (51.435 41.91)        MR180
R71      470R           R0603    resistor (57.785 41.91)        MR180
R72      470R           R0603    resistor (64.135 41.91)        MR180
R73      470R           R0603    resistor (70.485 41.91)        MR180
R74      0R             R1206    resistor (34.29 39.37)         MR90
R75      0R             R1206    resistor (40.64 39.37)         MR90
R76      0R             R1206    resistor (46.99 39.37)         MR90
R77      0R             R1206    resistor (53.34 39.37)         MR90
R78      0R             R1206    resistor (59.69 39.37)         MR90
R79      0R             R1206    resistor (66.04 39.37)         MR90
R81      470R           R0603    resistor (26.035 35.56)        MR180
R82      0R             R1206    resistor (27.94 33.02)         MR90
R83      470R           R0603    resistor (32.385 35.56)        MR180
R84      470R           R0603    resistor (38.735 35.56)        MR180
R85      470R           R0603    resistor (45.085 35.56)        MR180
R86      470R           R0603    resistor (51.435 35.56)        MR180
R87      470R           R0603    resistor (57.785 35.56)        MR180
R88      470R           R0603    resistor (64.135 35.56)        MR180
R89      470R           R0603    resistor (70.485 35.56)        MR180
R90      0R             R1206    resistor (34.29 33.02)         MR90
R91      0R             R1206    resistor (40.64 33.02)         MR90
R92      0R             R1206    resistor (46.99 33.02)         MR90
R93      0R             R1206    resistor (53.34 33.02)         MR90
R94      0R             R1206    resistor (59.69 33.02)         MR90
R95      0R             R1206    resistor (66.04 33.02)         MR90
R97      470R           R0603    resistor (26.035 29.21)        MR180
R98      0R             R1206    resistor (27.94 26.67)         MR90
R99      470R           R0603    resistor (32.385 29.21)        MR180
R100     470R           R0603    resistor (38.735 29.21)        MR180
R101     470R           R0603    resistor (45.085 29.21)        MR180
R102     470R           R0603    resistor (51.435 29.21)        MR180
R103     470R           R0603    resistor (57.785 29.21)        MR180
R104     470R           R0603    resistor (64.135 29.21)        MR180
R105     470R           R0603    resistor (70.485 29.21)        MR180
R106     0R             R1206    resistor (34.29 26.67)         MR90
R107     0R             R1206    resistor (40.64 26.67)         MR90
R108     0R             R1206    resistor (46.99 26.67)         MR90
R109     0R             R1206    resistor (53.34 26.67)         MR90
R110     0R             R1206    resistor (59.69 26.67)         MR90
R111     0R             R1206    resistor (66.04 26.67)         MR90
R113     470R           R0603    resistor (26.035 22.86)        MR180
R115     470R           R0603    resistor (32.385 22.86)        MR180
R116     470R           R0603    resistor (38.735 22.86)        MR180
R117     470R           R0603    resistor (45.085 22.86)        MR180
R118     470R           R0603    resistor (51.435 22.86)        MR180
R119     470R           R0603    resistor (57.785 22.86)        MR180
R120     470R           R0603    resistor (64.135 22.86)        MR180
R121     470R           R0603    resistor (70.485 22.86)        MR180

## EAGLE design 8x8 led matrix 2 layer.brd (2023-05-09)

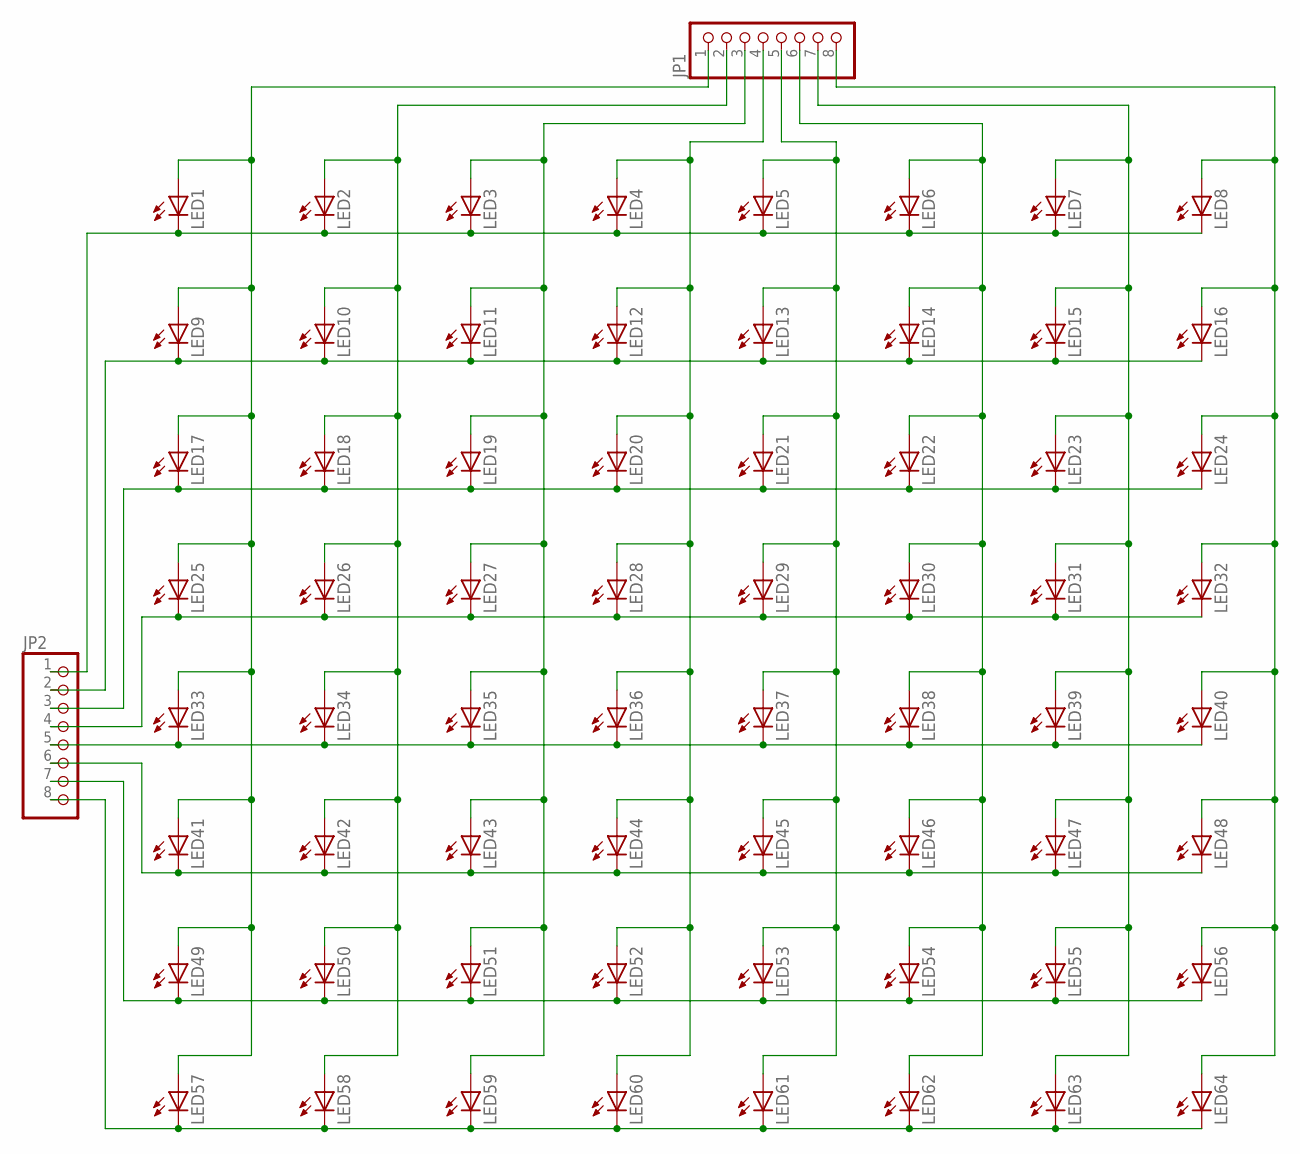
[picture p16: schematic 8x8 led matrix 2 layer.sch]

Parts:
JP1, JP2: PINHD-1X8; 1X08
LED1, LED2, LED3, LED4, LED5, LED6, LED7, LED8, LED9, LED10, LED11, LED12, LED13, LED14, LED15, LED16, LED17, LED18, LED19, LED20, LED21, LED22, LED23, LED24, LED25, LED26, LED27, LED28, LED29, LED30, LED31, LED32, LED33, LED34, LED35, LED36, LED37, LED38, LED39, LED40, LED41, LED42, LED43, LED44, LED45, LED46, LED47, LED48, LED49, LED50, LED51, LED52, LED53, LED54, LED55, LED56, LED57, LED58, LED59, LED60, LED61, LED62, LED63, LED64: LED5MM

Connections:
unnamed: JP1.4, LED4.A, LED12.A, LED20.A, LED28.A, LED36.A, LED44.A, LED52.A, LED60.A
unnamed: JP1.5, LED5.A, LED13.A, LED21.A, LED29.A, LED37.A, LED45.A, LED53.A, LED61.A
unnamed: JP1.1, LED1.A, LED9.A, LED17.A
unnamed: JP1.3, LED3.A, LED11.A, LED19.A, LED27.A, LED35.A, LED43.A, LED51.A, LED59.A
unnamed: JP1.6, LED6.A, LED14.A, LED22.A, LED30.A, LED38.A, LED46.A, LED54.A, LED62.A
unnamed: JP1.7, LED7.A, LED15.A, LED23.A, LED31.A, LED39.A, LED47.A, LED55.A, LED63.A
unnamed: JP2.1, LED1.K (C), LED2.K (C), LED3.K (C), LED4.K (C), LED5.K (C), LED6.K (C), LED7.K (C), LED8.K (C)
unnamed: JP2.2, LED9.K (C), LED10.K (C), LED11.K (C), LED12.K (C), LED13.K (C), LED14.K (C), LED15.K (C), LED16.K (C)
unnamed: JP2.3, LED17.K (C), LED18.K (C), LED19.K (C), LED20.K (C), LED21.K (C), LED22.K (C), LED23.K (C), LED24.K (C)
unnamed: LED25.A, LED33.A, LED41.A, LED49.A, LED57.A
unnamed: JP2.4, LED25.K (C), LED26.K (C), LED27.K (C), LED28.K (C), LED29.K (C), LED30.K (C), LED31.K (C), LED32.K (C)
unnamed: JP2.5, LED33.K (C), LED34.K (C), LED35.K (C), LED36.K (C), LED37.K (C), LED38.K (C), LED39.K (C), LED40.K (C)
unnamed: JP2.6, LED41.K (C), LED42.K (C), LED43.K (C), LED44.K (C), LED45.K (C), LED46.K (C), LED47.K (C), LED48.K (C)
unnamed: JP1.8, LED8.A, LED16.A, LED24.A, LED32.A, LED40.A, LED48.A, LED56.A, LED64.A
unnamed: JP2.7, LED49.K (C), LED50.K (C), LED51.K (C), LED52.K (C), LED53.K (C), LED54.K (C), LED55.K (C), LED56.K (C)
unnamed: JP1.2, LED2.A, LED10.A, LED18.A, LED26.A, LED34.A, LED42.A, LED50.A, LED58.A
unnamed: JP2.8, LED57.K (C), LED58.K (C), LED59.K (C), LED60.K (C), LED61.K (C), LED62.K (C), LED63.K (C), LED64.K (C)

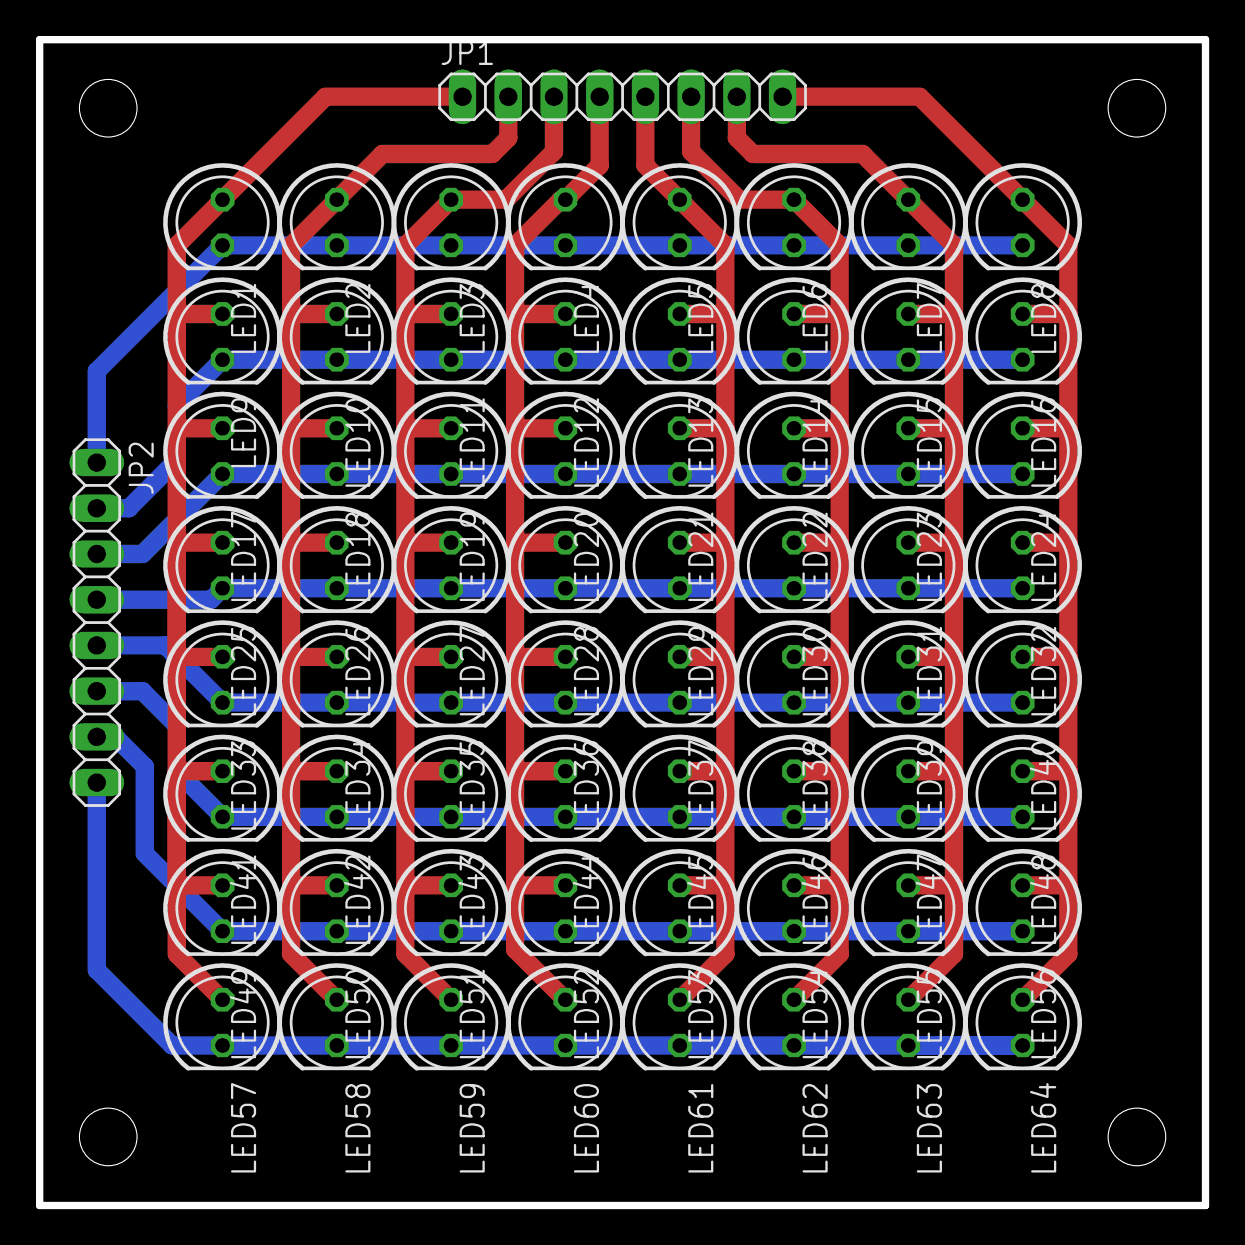
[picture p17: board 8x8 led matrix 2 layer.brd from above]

Board: 2 copper layers, 64.8 x 64.8 mm, 66 parts (0 on the bottom side), 17 nets.

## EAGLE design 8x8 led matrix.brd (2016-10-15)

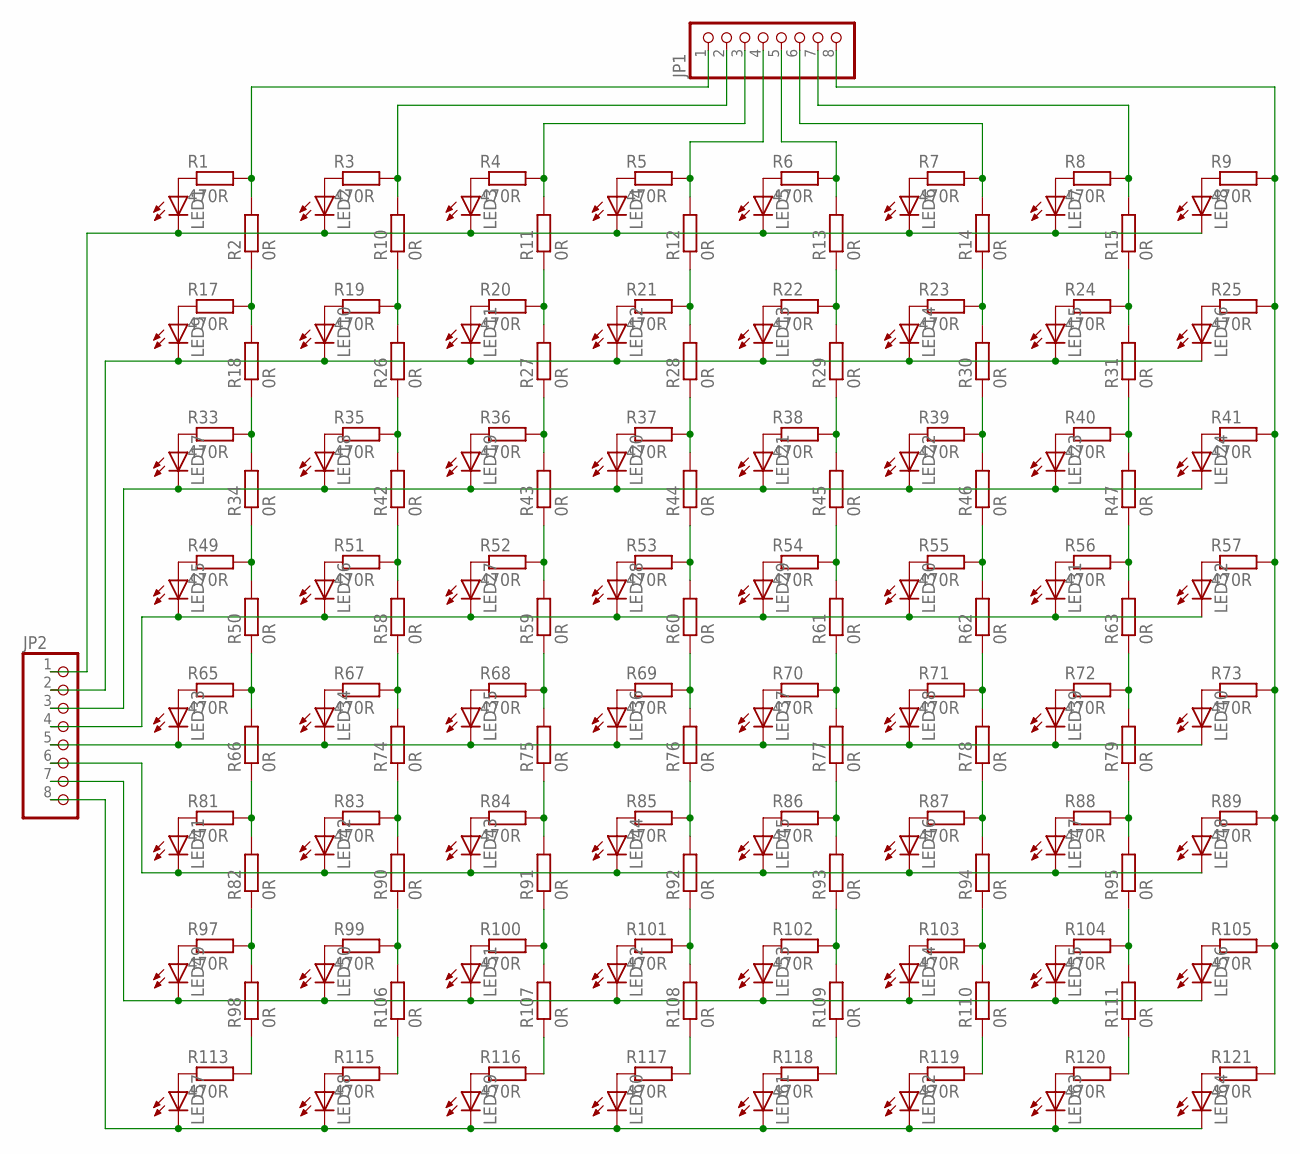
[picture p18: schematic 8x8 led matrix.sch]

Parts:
JP1, JP2: PINHD-1X8; 1X08
LED1, LED2, LED3, LED4, LED5, LED6, LED7, LED8, LED9, LED10, LED11, LED12, LED13, LED14, LED15, LED16, LED17, LED18, LED19, LED20, LED21, LED22, LED23, LED24, LED25, LED26, LED27, LED28, LED29, LED30, LED31, LED32, LED33, LED34, LED35, LED36, LED37, LED38, LED39, LED40, LED41, LED42, LED43, LED44, LED45, LED46, LED47, LED48, LED49, LED50, LED51, LED52, LED53, LED54, LED55, LED56, LED57, LED58, LED59, LED60, LED61, LED62, LED63, LED64: LED5MM
R1, R3, R4, R5, R6, R7, R8, R9, R17, R19, R20, R21, R22, R23, R24, R25, R33, R35, R36, R37, R38, R39, R40, R41, R49, R51, R52, R53, R54, R55, R56, R57, R65, R67, R68, R69, R70, R71, R72, R73, R81, R83, R84, R85, R86, R87, R88, R89, R97, R99, R100, R101, R102, R103, R104, R105, R113, R115, R116, R117, R118, R119, R120, R121: 470R; R0603
R2, R10, R11, R12, R13, R14, R15, R18, R26, R27, R28, R29, R30, R31, R34, R42, R43, R44, R45, R46, R47, R50, R58, R59, R60, R61, R62, R63, R66, R74, R75, R76, R77, R78, R79, R82, R90, R91, R92, R93, R94, R95, R98, R106, R107, R108, R109, R110, R111: 0R; R1206

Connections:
unnamed: LED1.A, R1.1
unnamed: LED2.A, R3.1
unnamed: LED3.A, R4.1
unnamed: LED4.A, R5.1
unnamed: LED5.A, R6.1
unnamed: LED6.A, R7.1
unnamed: LED7.A, R8.1
unnamed: LED8.A, R9.1
unnamed: JP1.4, R5.2, R12.2
unnamed: JP1.5, R6.2, R13.2
unnamed: JP1.1, R1.2, R2.2
unnamed: JP1.2, R3.2, R10.2
unnamed: JP1.3, R4.2, R11.2
unnamed: JP1.6, R7.2, R14.2
unnamed: JP1.7, R8.2, R15.2
unnamed: JP2.1, LED1.K (C), LED2.K (C), LED3.K (C), LED4.K (C), LED5.K (C), LED6.K (C), LED7.K (C), LED8.K (C)
unnamed: LED9.A, R17.1
unnamed: LED10.A, R19.1
unnamed: LED11.A, R20.1
unnamed: LED12.A, R21.1
unnamed: LED13.A, R22.1
unnamed: LED14.A, R23.1
unnamed: LED15.A, R24.1
unnamed: LED16.A, R25.1
unnamed: R2.1, R17.2, R18.2
unnamed: R10.1, R19.2, R26.2
unnamed: R11.1, R20.2, R27.2
unnamed: R12.1, R21.2, R28.2
unnamed: R13.1, R22.2, R29.2
unnamed: R14.1, R23.2, R30.2
unnamed: R15.1, R24.2, R31.2
unnamed: JP2.2, LED9.K (C), LED10.K (C), LED11.K (C), LED12.K (C), LED13.K (C), LED14.K (C), LED15.K (C), LED16.K (C)
unnamed: LED17.A, R33.1
unnamed: LED18.A, R35.1
unnamed: LED19.A, R36.1
unnamed: LED20.A, R37.1
unnamed: LED21.A, R38.1
unnamed: LED22.A, R39.1
unnamed: LED23.A, R40.1
unnamed: LED24.A, R41.1
unnamed: R18.1, R33.2, R34.2
unnamed: R26.1, R35.2, R42.2
unnamed: R27.1, R36.2, R43.2
unnamed: R28.1, R37.2, R44.2
unnamed: R29.1, R38.2, R45.2
unnamed: R30.1, R39.2, R46.2
unnamed: R31.1, R40.2, R47.2
unnamed: JP2.3, LED17.K (C), LED18.K (C), LED19.K (C), LED20.K (C), LED21.K (C), LED22.K (C), LED23.K (C), LED24.K (C)
unnamed: LED25.A, R49.1
unnamed: LED26.A, R51.1
unnamed: LED27.A, R52.1
unnamed: LED28.A, R53.1
unnamed: LED29.A, R54.1
unnamed: LED30.A, R55.1
unnamed: LED31.A, R56.1
unnamed: LED32.A, R57.1
unnamed: R34.1, R49.2, R50.2
unnamed: R42.1, R51.2, R58.2
unnamed: R43.1, R52.2, R59.2
unnamed: R44.1, R53.2, R60.2
unnamed: R45.1, R54.2, R61.2
unnamed: R46.1, R55.2, R62.2
unnamed: R47.1, R56.2, R63.2
unnamed: JP2.4, LED25.K (C), LED26.K (C), LED27.K (C), LED28.K (C), LED29.K (C), LED30.K (C), LED31.K (C), LED32.K (C)
unnamed: LED33.A, R65.1
unnamed: LED34.A, R67.1
unnamed: LED35.A, R68.1
unnamed: LED36.A, R69.1
unnamed: LED37.A, R70.1
unnamed: LED38.A, R71.1
unnamed: LED39.A, R72.1
unnamed: LED40.A, R73.1
unnamed: R50.1, R65.2, R66.2
unnamed: R58.1, R67.2, R74.2
unnamed: R59.1, R68.2, R75.2
unnamed: R60.1, R69.2, R76.2
unnamed: R61.1, R70.2, R77.2
unnamed: R62.1, R71.2, R78.2
unnamed: R63.1, R72.2, R79.2
unnamed: JP2.5, LED33.K (C), LED34.K (C), LED35.K (C), LED36.K (C), LED37.K (C), LED38.K (C), LED39.K (C), LED40.K (C)
unnamed: LED41.A, R81.1
unnamed: LED42.A, R83.1
unnamed: LED43.A, R84.1
unnamed: LED44.A, R85.1
unnamed: LED45.A, R86.1
unnamed: LED46.A, R87.1
unnamed: LED47.A, R88.1
unnamed: LED48.A, R89.1
unnamed: R66.1, R81.2, R82.2
unnamed: R74.1, R83.2, R90.2
unnamed: R75.1, R84.2, R91.2
unnamed: R76.1, R85.2, R92.2
unnamed: R77.1, R86.2, R93.2
unnamed: R78.1, R87.2, R94.2
unnamed: R79.1, R88.2, R95.2
unnamed: JP2.6, LED41.K (C), LED42.K (C), LED43.K (C), LED44.K (C), LED45.K (C), LED46.K (C), LED47.K (C), LED48.K (C)
unnamed: LED49.A, R97.1
unnamed: LED50.A, R99.1
unnamed: LED51.A, R100.1
unnamed: LED52.A, R101.1
unnamed: LED53.A, R102.1
unnamed: LED54.A, R103.1
unnamed: LED55.A, R104.1
unnamed: LED56.A, R105.1
unnamed: R82.1, R97.2, R98.2
unnamed: R90.1, R99.2, R106.2
unnamed: R91.1, R100.2, R107.2
unnamed: R92.1, R101.2, R108.2
unnamed: R93.1, R102.2, R109.2
unnamed: R94.1, R103.2, R110.2
unnamed: R95.1, R104.2, R111.2
unnamed: JP1.8, R9.2, R25.2, R41.2, R57.2, R73.2, R89.2, R105.2, R121.2
unnamed: JP2.7, LED49.K (C), LED50.K (C), LED51.K (C), LED52.K (C), LED53.K (C), LED54.K (C), LED55.K (C), LED56.K (C)
unnamed: LED57.A, R113.1
unnamed: LED58.A, R115.1
unnamed: LED59.A, R116.1
unnamed: LED60.A, R117.1
unnamed: LED61.A, R118.1
unnamed: LED62.A, R119.1
unnamed: LED63.A, R120.1
unnamed: LED64.A, R121.1
unnamed: R98.1, R113.2
unnamed: R106.1, R115.2
unnamed: R107.1, R116.2
unnamed: R108.1, R117.2
unnamed: R109.1, R118.2
unnamed: R110.1, R119.2
unnamed: R111.1, R120.2
unnamed: JP2.8, LED57.K (C), LED58.K (C), LED59.K (C), LED60.K (C), LED61.K (C), LED62.K (C), LED63.K (C), LED64.K (C)

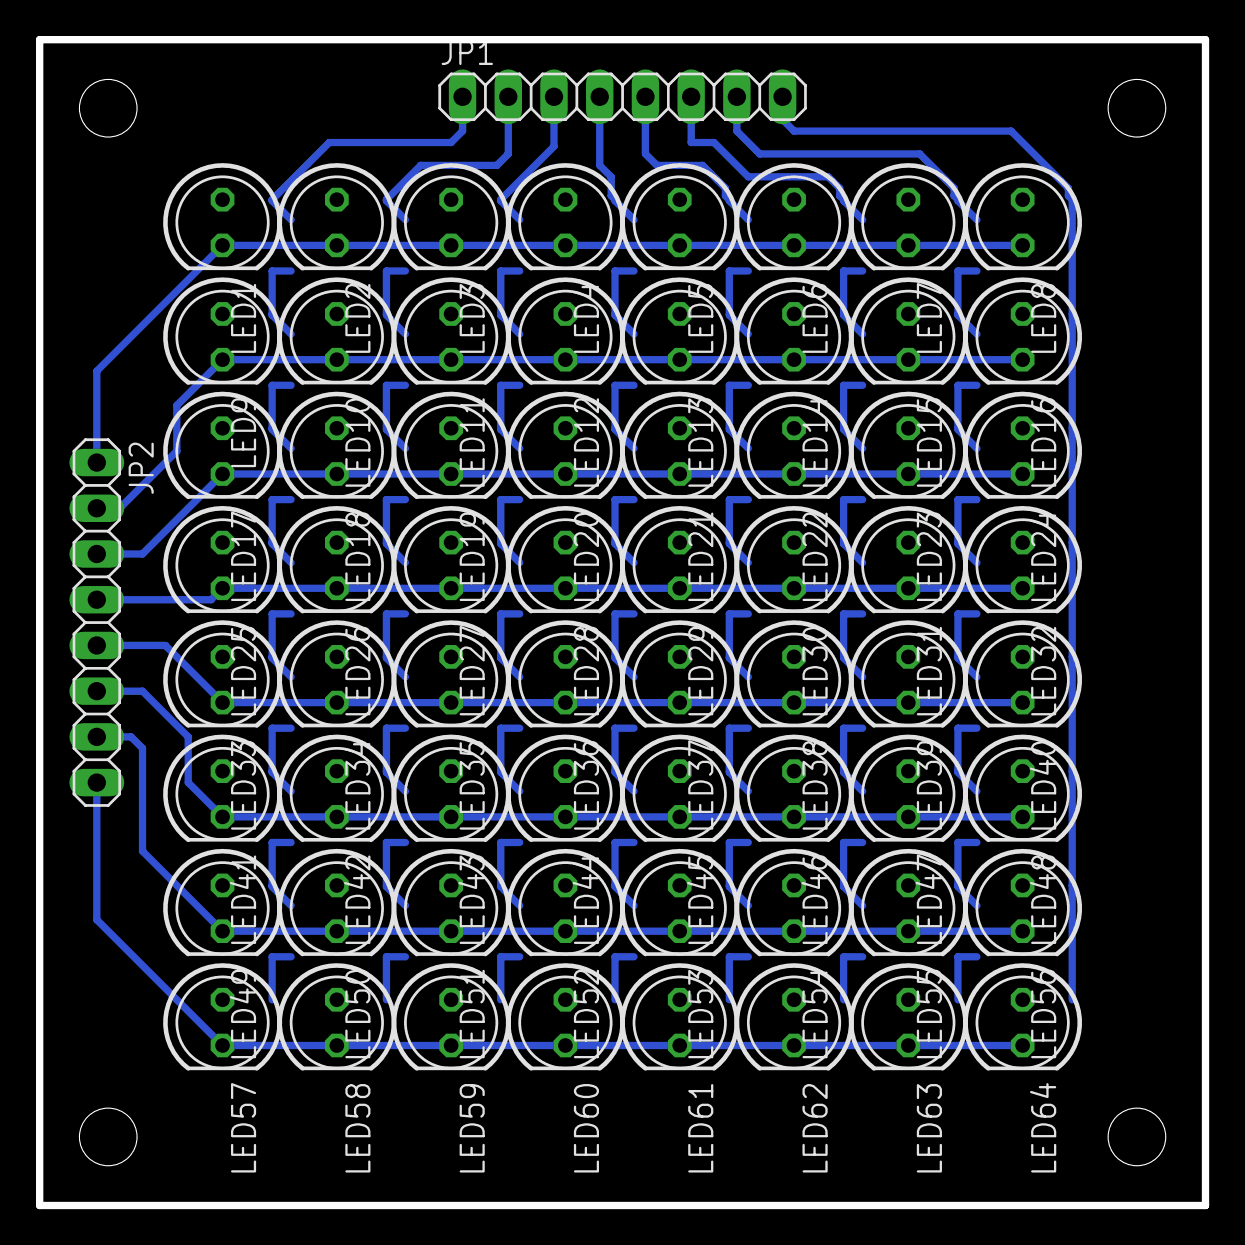
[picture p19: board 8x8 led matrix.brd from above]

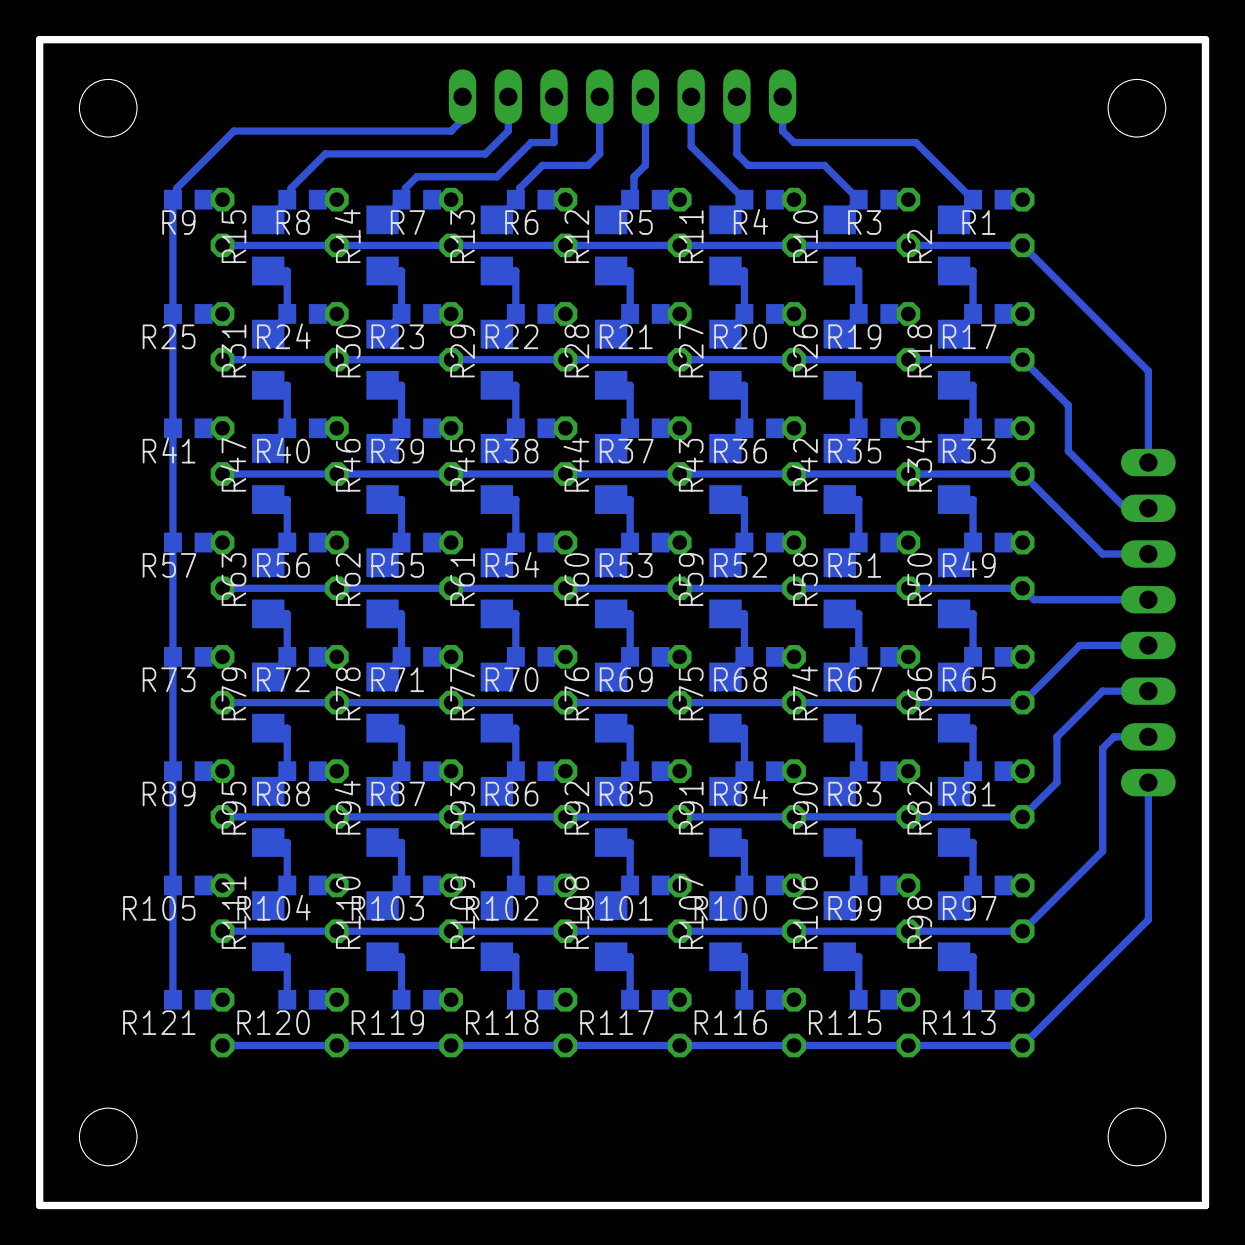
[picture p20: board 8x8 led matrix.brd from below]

Board: 2 copper layers, 64.8 x 64.8 mm, 179 parts (113 on the bottom side), 129 nets.

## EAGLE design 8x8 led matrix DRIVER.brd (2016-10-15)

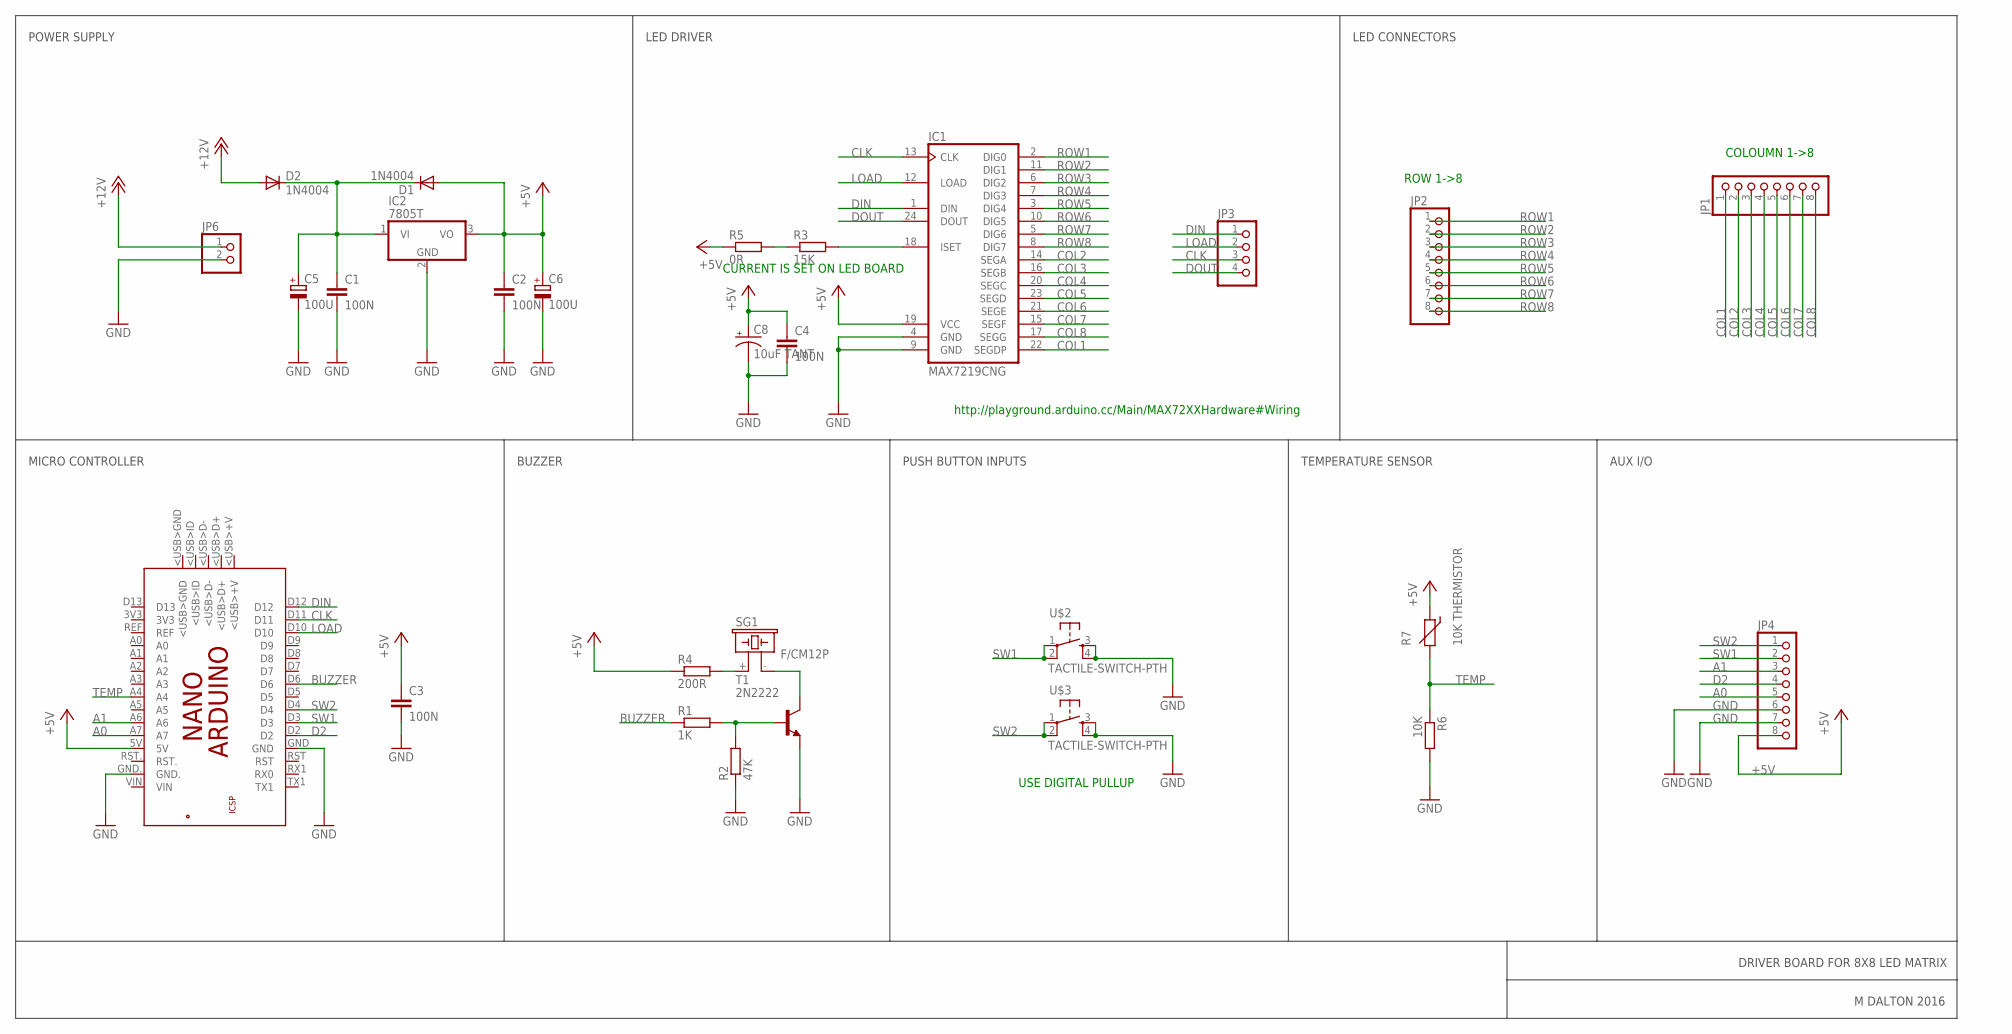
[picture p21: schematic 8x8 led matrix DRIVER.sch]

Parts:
C1, C2, C3, C4: 100N; C1206K
C5, C6: 100U; E5-10,5
C8: 10uF TANT; EIA3216
D1, D2: 1N4004; DO41-10
IC1: MAX7219CNG; DIL24-3
IC2: 7805T; TO220H
JP1, JP2, JP4: PINHD-1X8; 1X08
JP3: PINHD-1X4; 1X04
JP6: PINHD-1X2; 1X02
PCB1: ARDUINO_NANO
R1: 1K; M1206
R2: 47K; M1206
R3: 15K; M0805
R4: 200R; M1206
R5: 0R; M0805
R6: 10K; M1206
R7: 10K THERMISTOR; R-7,5
SG1: F/CM12P
T1: 2N2222; TO92-EBC-OVAL
U$2, U$3: TACTILE-SWITCH-PTH; TAC-SWITCH-PTH

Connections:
+5V: C2.1, C3.1, C4.1, C6.+, C8.A (+), D1.A, IC1.19 (VCC), IC2.3 (VO), JP4.8, PCB1.5V, R4.1, R5.1, R7.1
+12V: D2.A, JP6.1
A0: JP4.5, PCB1.A7
A1: JP4.3, PCB1.A6
BUZZER: PCB1.D6, R1.1
CLK: IC1.13 (CLK), JP3.3, PCB1.D11
COL1: IC1.22 (SEGDP), JP1.1
COL2: IC1.14 (SEGA), JP1.2
COL3: IC1.16 (SEGB), JP1.3
COL4: IC1.20 (SEGC), JP1.4
COL5: IC1.23 (SEGD), JP1.5
COL6: IC1.21 (SEGE), JP1.6
COL7: IC1.15 (SEGF), JP1.7
COL8: IC1.17 (SEGG), JP1.8
D2: JP4.4, PCB1.D2
DIN: IC1.1 (DIN), JP3.1, PCB1.D12
DOUT: IC1.24 (DOUT), JP3.4
GND: C1.2, C2.2, C3.2, C4.2, C5.-, C6.-, C8.C (-), IC1.4 (GND), IC1.9 (GND), IC2.2 (GND), JP4.6, JP4.7, JP6.2, PCB1.GND, PCB1.GND., R2.1, R6.2, T1.E, U$2.3, U$2.4, U$3.3, U$3.4
LOAD: IC1.12 (LOAD), JP3.2, PCB1.D10
unnamed: R3.1, R5.2
unnamed: C1.1, C5.+, D1.C, D2.C, IC2.1 (VI)
unnamed: IC1.18 (ISET), R3.2
unnamed: R1.2, R2.2, T1.B
unnamed: SG1.- (2), T1.C
unnamed: R4.2, SG1.+ (1)
ROW1: IC1.2 (DIG0), JP2.1
ROW2: IC1.11 (DIG1), JP2.2
ROW3: IC1.6 (DIG2), JP2.3
ROW4: IC1.7 (DIG3), JP2.4
ROW5: IC1.3 (DIG4), JP2.5
ROW6: IC1.10 (DIG5), JP2.6
ROW7: IC1.5 (DIG6), JP2.7
ROW8: IC1.8 (DIG7), JP2.8
SW1: JP4.2, PCB1.D3, U$2.1, U$2.2
SW2: JP4.1, PCB1.D4, U$3.1, U$3.2
TEMP: PCB1.A4, R6.1, R7.2

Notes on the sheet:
ROW 1->8
COLOUMN 1->8
http://playground.arduino.cc/Main/MAX72XXHardware#Wiring
CURRENT IS SET ON LED BOARD
USE DIGITAL PULLUP
POWER SUPPLY
LED DRIVER
LED CONNECTORS
MICRO CONTROLLER
BUZZER
PUSH BUTTON INPUTS
TEMPERATURE SENSOR
AUX I/O
DRIVER BOARD FOR 8X8 LED MATRIX
M DALTON 2016

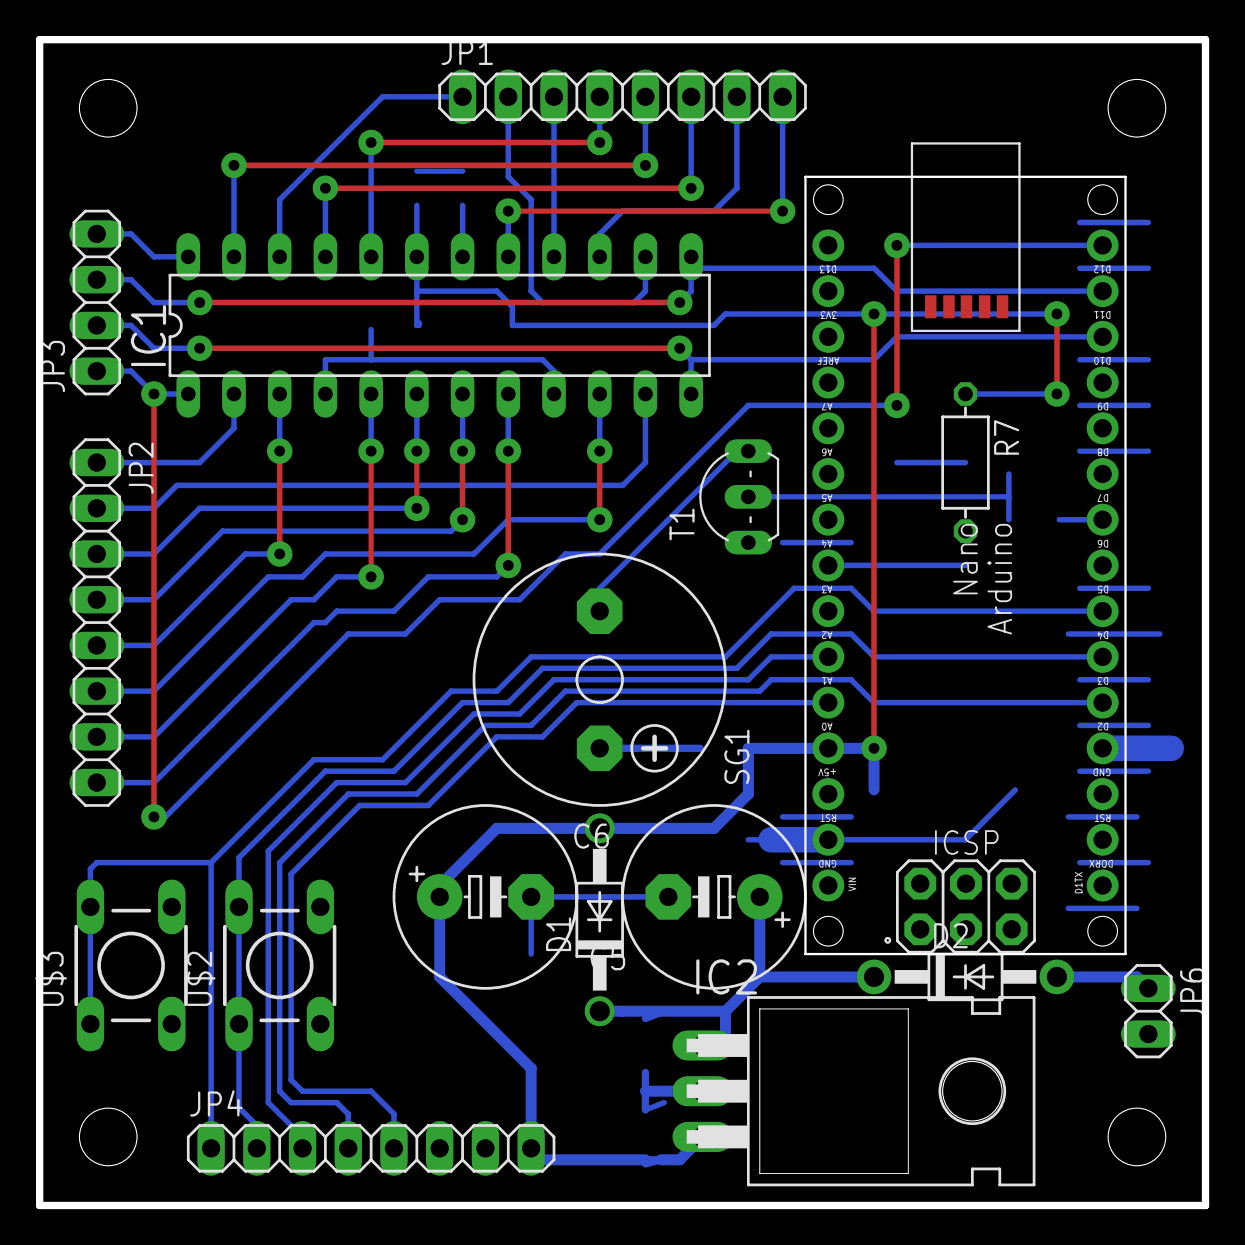
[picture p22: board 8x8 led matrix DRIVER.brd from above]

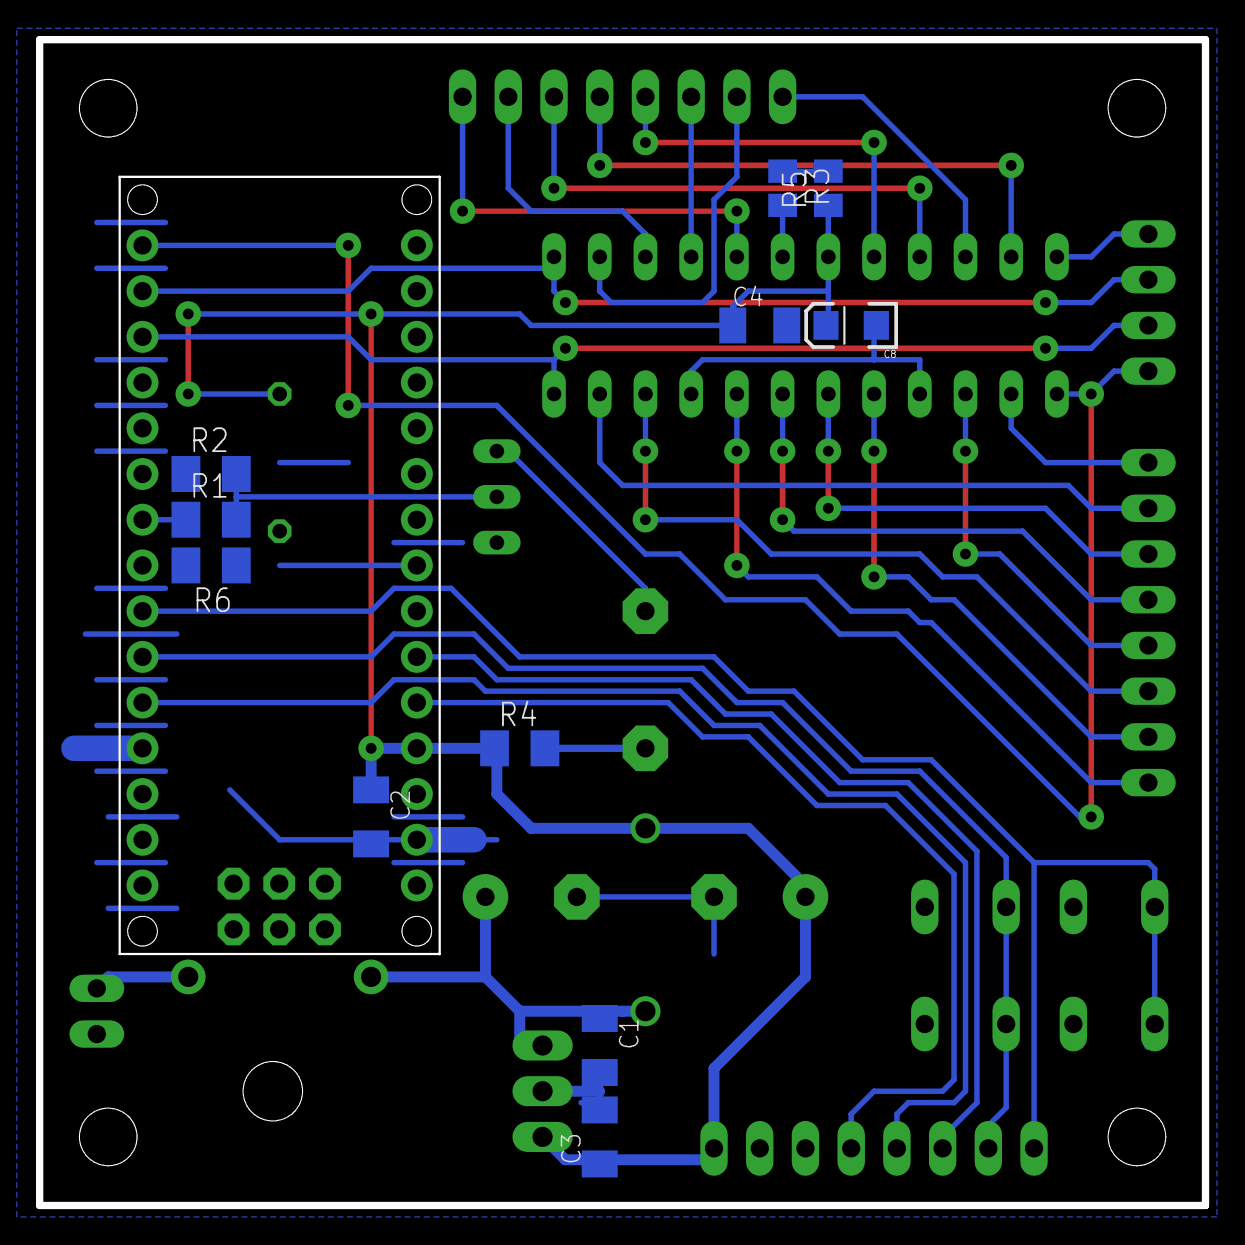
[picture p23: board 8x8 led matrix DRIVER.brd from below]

Board: 2 copper layers, 64.8 x 64.8 mm, 28 parts (11 on the bottom side), 36 nets.

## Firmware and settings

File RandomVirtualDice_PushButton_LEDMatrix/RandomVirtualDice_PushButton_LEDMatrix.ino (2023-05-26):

// Random Generated Virtual Dice displayed on 8x8 LED Matrix activated by push-button
// 
//
//                                               Stefan Alexandru, May 26th 2023
//

#include <MaxMatrix.h>  // Imported library that contains required matrix and LED controller functions

int button = 4;  // Sets button to appropriate button pin
long randNumber;  //  Defines variable as long number (-2,147,483,648 to 2,147,483,647)

int data = 12;  // Sets data to the DIN pin on MAX7219 module
int load = 10;  // Sets load to the CS pin on the MAX7219 module
int clock = 11;  // Sets clock to the CLK pin on the MAX7219 module
int maxInUse = 1;   // Variable to set how many MAX7219's you'll use

MaxMatrix m(data, load, clock, maxInUse);  // Defines the module

char one[] = {2, 8, B00011000, B00011000,};  // How dice NO. one is displayed on the 8x8 LED Matrix
char two[] = {6, 8, B00011000, B00011000, B00000000, B00000000, B00011000, B00011000};  // How dice NO. two is displayed on the 8x8 LED Matrix
char three[] = {6, 8, B00000110, B00000110, B01100000, B01100000, B00000110, B00000110,};  // How dice NO. three is displayed on the 8x8 LED Matrix
char four[] = {6, 8, B01100110, B01100110, B00000000, B00000000, B01100110, B01100110,};  // How dice NO. four is displayed on the 8x8 LED Matrix
char five[] = {6, 8, B01100110, B01100110, B00011000, B00011000, B01100110, B01100110,};  // How dice NO. five is displayed on the 8x8 LED Matrix
char six[] = {6, 8, B11011011, B11011011, B00000000, B00000000, B11011011, B11011011,};  // How dice NO. six is displayed on the 8x8 LED Matrix
char test[] = {8, 8, B11111111, B11111111, B11111111, B11111111, B11111111, B11111111, B11111111, B11111111,};  // Turns all the LEDs on - to see if they all work properly

void setup()
{
  m.init();  // Function to initialise the LED module
  m.setIntensity(15);  // Dot matrix light intensity 0-15
  Serial.begin(9600);  // Opens Serial Communication, sets data rate to 9600 bps
  pinMode(button, INPUT_PULLUP);  // Defines button as an input

  //  Defines where seed for ran.num.gen is picked up from
  //  Generates different seed numbers each time sketch runs
  //  Since pin is floating value that will seed the ran.num.gen will never be the same thus making it truly random
  randomSeed(analogRead(0));
}

void loop()
{
  int buttonState = digitalRead(button);  // Reads new state of button
  if (buttonState == LOW)
  {
    Serial.println("The BUTTON has been pressed");
    randomNumber();  // Calls the randomNumber function below
    whatNumber();  // Calls the whatNumber function below
  }
}

void randomNumber()  // Defines the randomNumber function - random number generator
{
  randNumber = random(1, 7);  // Generates a random number from 1 to 7
  delay(100);  // Delays next operation by 0.1s 
  Serial.println(randNumber);  // Prints the random number that has been generated in the serial monitor
}

void whatNumber()  //  Defines the whatNumber function - what happens depending on the number generated
{
  if (randNumber == 1)  // When the random number generated is 1 then:
  {
    m.writeSprite(3,0,one);  // Displays the dice NO. one on LED display
    delay(3000);  // Delays next operation by 3s - meaning before image clears it is displayed for 3s
    m.clear();  // Clears the image
  }
  if (randNumber == 2)
  {
    m.writeSprite(1,0,two);
    delay(3000);
    m.clear();
  }
  if (randNumber == 3)
  {
    m.writeSprite(1,0,three);
    delay(3000);
    m.clear();
  }
  if (randNumber == 4)
  {
    m.writeSprite(1,0,four);
    delay(3000);
    m.clear();
  }
  if (randNumber == 5)
  {
    m.writeSprite(1,0,five);
    delay(3000);
    m.clear();
  }
  if (randNumber == 6)
  {
    m.writeSprite(1,0,six);
    delay(3000);
    m.clear();
  }
}

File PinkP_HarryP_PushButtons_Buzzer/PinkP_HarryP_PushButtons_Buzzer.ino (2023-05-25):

//
//  Push-Button activated Buzzer that has two outputs button1 - Harry Potter song and button2 - Pink Panther song
//
//                                                    Stefan Alexandru, May 24th 2023
//

#include <pitches.h>  // Imported library that contains required notes, etc. for song
#define REST 0  // Defines REST, the library doesn't include REST

const int buzzer = 6;  // Sets buzzer to the buzzer pin
const int button1 = 3;  // Sets push-button1 to the appropriate button pin
const int button2 = 4;  // Sets push-button2 to the appropriate button pin

int tempoH = 144;  // Sets the speed of Harry Potter
int tempoP = 120;  // Sets the speed of Pink Panther


// Notes of the melody + Note durations
// e.g 4 =  quarter note, 8 = eighteenth, -4 = dotted quarter note
int melodyH[] = 
{

  // Harry Potter theme song

  REST, 2, NOTE_D4, 4,
  NOTE_G4, -4, NOTE_AS4, 8, NOTE_A4, 4,
  NOTE_G4, 2, NOTE_D5, 4,
  NOTE_C5, -2, 
  NOTE_A4, -2,
  NOTE_G4, -4, NOTE_AS4, 8, NOTE_A4, 4,
  NOTE_F4, 2, NOTE_GS4, 4,
  NOTE_D4, -1, 
  NOTE_D4, 4,

  NOTE_G4, -4, NOTE_AS4, 8, NOTE_A4, 4, //10
  NOTE_G4, 2, NOTE_D5, 4,
  NOTE_F5, 2, NOTE_E5, 4,
  NOTE_DS5, 2, NOTE_B4, 4,
  NOTE_DS5, -4, NOTE_D5, 8, NOTE_CS5, 4,
  NOTE_CS4, 2, NOTE_B4, 4,
  NOTE_G4, -1,
  NOTE_AS4, 4,
     
  NOTE_D5, 2, NOTE_AS4, 4,//18
  NOTE_D5, 2, NOTE_AS4, 4,
  NOTE_DS5, 2, NOTE_D5, 4,
  NOTE_CS5, 2, NOTE_A4, 4,
  NOTE_AS4, -4, NOTE_D5, 8, NOTE_CS5, 4,
  NOTE_CS4, 2, NOTE_D4, 4,
  NOTE_D5, -1, 
  REST,4, NOTE_AS4,4,  

  NOTE_D5, 2, NOTE_AS4, 4,//26
  NOTE_D5, 2, NOTE_AS4, 4,
  NOTE_F5, 2, NOTE_E5, 4,
  NOTE_DS5, 2, NOTE_B4, 4,
  NOTE_DS5, -4, NOTE_D5, 8, NOTE_CS5, 4,
  NOTE_CS4, 2, NOTE_AS4, 4,
  NOTE_G4, -1,  
};

// Notes of the melody + Note durations
// e.g 4 =  quarter note, 8 = eighteenth, -4 = dotted quarter note
int melodyP[] =
{

  // Pink Panther theme song

  REST,2, REST,4, REST,8, NOTE_DS4,8, 
  NOTE_E4,-4, REST,8, NOTE_FS4,8, NOTE_G4,-4, REST,8, NOTE_DS4,8,
  NOTE_E4,-8, NOTE_FS4,8,  NOTE_G4,-8, NOTE_C5,8, NOTE_B4,-8, NOTE_E4,8, NOTE_G4,-8, NOTE_B4,8,   
  NOTE_AS4,2, NOTE_A4,-16, NOTE_G4,-16, NOTE_E4,-16, NOTE_D4,-16, 
  NOTE_E4,2, REST,4, REST,8, NOTE_DS4,4,

  NOTE_E4,-4, REST,8, NOTE_FS4,8, NOTE_G4,-4, REST,8, NOTE_DS4,8,
  NOTE_E4,-8, NOTE_FS4,8,  NOTE_G4,-8, NOTE_C5,8, NOTE_B4,-8, NOTE_G4,8, NOTE_B4,-8, NOTE_E5,8,
  NOTE_DS5,1,   
  NOTE_D5,2, REST,4, REST,8, NOTE_DS4,8, 
  NOTE_E4,-4, REST,8, NOTE_FS4,8, NOTE_G4,-4, REST,8, NOTE_DS4,8,
  NOTE_E4,-8, NOTE_FS4,8,  NOTE_G4,-8, NOTE_C5,8, NOTE_B4,-8, NOTE_E4,8, NOTE_G4,-8, NOTE_B4,8,   
  
  NOTE_AS4,2, NOTE_A4,-16, NOTE_G4,-16, NOTE_E4,-16, NOTE_D4,-16, 
  NOTE_E4,-4, REST,4,
  REST,4, NOTE_E5,-8, NOTE_D5,8, NOTE_B4,-8, NOTE_A4,8, NOTE_G4,-8, NOTE_E4,-8,
  NOTE_AS4,16, NOTE_A4,-8, NOTE_AS4,16, NOTE_A4,-8, NOTE_AS4,16, NOTE_A4,-8, NOTE_AS4,16, NOTE_A4,-8,   
  NOTE_G4,-16, NOTE_E4,-16, NOTE_D4,-16, NOTE_E4,16, NOTE_E4,16, NOTE_E4,2,
};

// For Harry Potter
int notesH = sizeof(melodyH) / sizeof(melodyH[0]) / 2;  // sizeof() gives the number of bytes, each int has two bytes - there are two values per note therefore each note is four bytes
int wholenoteH = (60000 * 4) / tempoH;  // Calculates the duration of a whole note in ms (60s / tempo)*4 beats
int dividerH = 0, noteDurationH = 0;  // Variables

// For Pink Panther
int notesP = sizeof(melodyP) / sizeof(melodyP[0]) / 2;
int wholenoteP = (60000 * 4) / tempoP;
int dividerP = 0, noteDurationP = 0;

void setup() 
{
  Serial.begin(9600);  // Opens Serial Communication, sets data rate to 9600 bps
  pinMode(button1, INPUT_PULLUP);  // Defines button1 as an input
  pinMode(button2, INPUT_PULLUP);  // Defines button2 as an input
}

void loop()
{
  int buttonStateH = digitalRead(button1);  // Reads new state of button1
  if (buttonStateH == LOW)
  {
    Serial.println("BUTTON 1 has been pressed");
    buzzerH(); // Calls the buzzerH function below
  }

  int buttonStateP = digitalRead(button2);  // Reads new state of button2
  if (buttonStateP == LOW)
  {
    Serial.println("BUTTON 2 has been pressed");
    buzzerP(); // Calls the buzzerP function below
  }
} 

void buzzerH()
{
  // Iterate over the notes of the melody. 
  // Remember, the array is twice the number of notes (melody notes + note durations)
  for (int thisNoteH = 0; thisNoteH < notesH * 2; thisNoteH = thisNoteH + 2) 
  {
    dividerH = melodyH[thisNoteH + 1];  // Calculates the duration ofr each note
    if (dividerH > 0)
    {
      noteDurationH = (wholenoteH) / dividerH;
    } 
    else if (dividerH < 0) 
    {
      noteDurationH = (wholenoteH) / abs(dividerH);  // Dotted notes are represented with negatice duartions
      noteDurationH *= 1.5;  // Increases the duration by 50% for dotted notes
    }
    tone(buzzer, melodyH[thisNoteH], noteDurationH*0.9);  // Note only plays 90% of the duartion, leaving 10% as a pause
    delay(noteDurationH);  // Wait for the specified duartion before playing the next note
    noTone(buzzer);  // After all notes are played tone stops
  }
}

// All comments used for buzzerH apply for buzzerP
void buzzerP()
{
  for (int thisNoteP = 0; thisNoteP < notesP * 2; thisNoteP = thisNoteP + 2) 
  {
    dividerP = melodyP[thisNoteP + 1];
    if (dividerP > 0) 
    {
      noteDurationP = (wholenoteP) / dividerP;
    } 
    else if (dividerP < 0)
    {
      noteDurationP = (wholenoteP) / abs(dividerP);
      noteDurationP *= 1.5; 
    }
    tone(buzzer, melodyP[thisNoteP], noteDurationP*0.9);
    delay(noteDurationP);
    noTone(buzzer);
  }
}

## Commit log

2023-05-09 Add files via upload
    2 layer PCB
    [8x8 led matrix 2 layer.brd, 8x8 led matrix 2 layer.sch]
2023-05-25 Add files via upload
    Push-button buzzer code to turn on the buzzer at the press of the button. This code makes use of simple PWM using analogWrite() because the buzzer I am using (ABT-414-RC) cannot use DC current hence can't make use of the digitalWrite() function to turn it on and off. Expected Result - when button is pushed the buzzer will turn on and when button is released the buzzer will turn off.

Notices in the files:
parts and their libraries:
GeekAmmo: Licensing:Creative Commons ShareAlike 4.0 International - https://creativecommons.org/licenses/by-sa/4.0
